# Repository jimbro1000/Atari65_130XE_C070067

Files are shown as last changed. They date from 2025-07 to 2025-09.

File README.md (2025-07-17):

# Atari 65/130XE Reproduction

## Introduction

This project reproduces the PCB used in the Atari 65XE and 130XE.
There are several variations on the board, this targets the
earlier design that used 8 or 16 4164 DRAM chips. These boards are
marked as C070065 or C070067

The initial primary goal is to support diagnostics rather than
create replacement boards but this will likely become possible as 
the project progresses.

### Sponsorship and Support

A bare donor board has been provided by Lee of "More Fun Making It"
and founder of the Retro Hardware Discord to save my working board 
from being torn down.

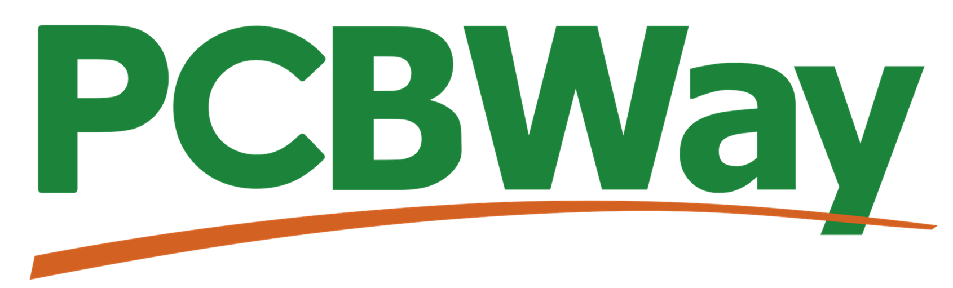
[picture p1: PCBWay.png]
PCBWay Logo


PCBWay are sponsoring the initial fabrication of the board by covering
the costs and providing high quality, rapid turnaround prototyping
capabilities.

An honourable mention also goes to Henry of the Retro Hardware Discord
for providing spares to help fix my 65XE (and thus negating the direct 
need for any of the work here)

### Sources

The schematics that the design is taken from are themselves copies
of the original work.

The primary source of information is taken from an updated version
of the Atari workshop manual updated and reproduced by JER/Eightbitter.
A second source comes from earlier reproduction drawings by Jerzy Sobola.

## Interactive Bill of Materials

The initial output of the project will be a web based interactive bill
of materials that includes trace routing. This allows visual 
identification of individual traces on the board and the devices each
trace connects to.

## Engineering Files

Once the accuracy of the reproduction is verified the project output
will include gerber files to facilitate the fabrication of boards.

### Accuracy

While every effort is made to ensure that the board design is accurate
and faithful to the original, there will be variations in tolerances that
result in the need for fettling of the board to correctly fit the
original case.

The board design provided will be a direct copy in terms of the components
used and as such will require original parts, some of which are
effectively unobtainable other than from donor machines - notably the SIO
port, expansion port and half of the custom chips. 

The SALLY CPU chip can be replaced with an adapted 65C02 to add the missing
HALT signal. FREDDIE and POKEY are available as reproductions. The PIA can 
be replaced with a MC68B21 (or equivalent).

## Progress

Revision 1 of the schematics and board design is complete, awaiting fabrication and test. Some tweaks to the schematic have been made to
match the donor board. The factory bodge for the GTIA select line has
been incorporated into the design, this has resulted in some 
alterations to routing but leaves a much tidier board when completed.

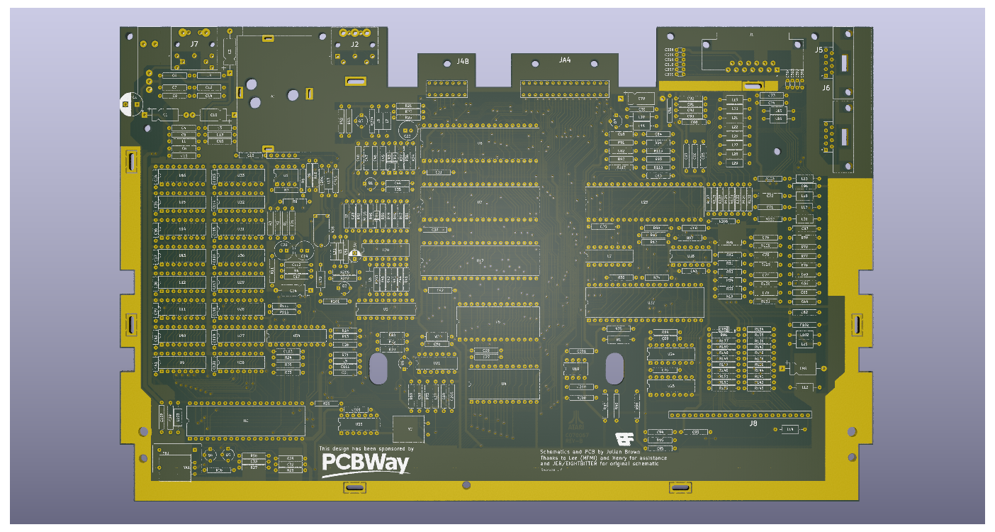
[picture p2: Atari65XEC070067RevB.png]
Render of PCB top


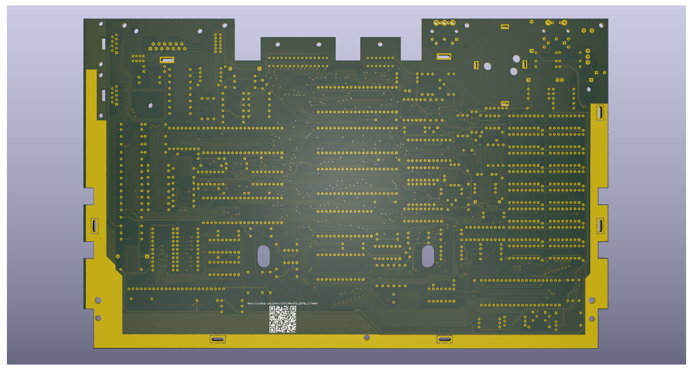
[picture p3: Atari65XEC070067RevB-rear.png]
Render of PCB rear


## References

FREDDIE replacement - design by Candle'O'Sin. Sold by Retro Lemon in two 
flavours:  
* https://retrolemon.co.uk/atari-8bit-upgrades/182-freddie-cpld.html
* https://retrolemon.co.uk/atari-8bit-upgrades/81-freddie-module.html
  (only for use with matching SRAM module)

SALLY conversion - open source project you can fabricate (or have fabricated 
for you)
* https://github.com/TheByteAttic/Sally-to-W65C02S-adapter
* https://www.pcbway.com/project/shareproject/6502__W65C02S__to_Atari_SALLY_adapter_Board.html

POKEY replacement (and upgrade) - design by Retronics. Sold by Retro Lemon:
* https://retrolemon.co.uk/atari-8bit-upgrades/148-pokeymax.html

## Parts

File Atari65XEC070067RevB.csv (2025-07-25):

Reference | Qty | Value | Footprint | DigiKey
C1 | 1 | 470uF | Capacitor_THT:CP_Radial_D10.0mm_P5.00mm | 732-9156-1-ND
C2,C3,C10,C79 | 4 | 22uF | Capacitor_THT:CP_Axial_L11.0mm_D5.0mm_P18.00mm_Horizontal | 1572-1393-ND
C4,C13,C16,C18,C26,C27,C28,C29,C30,C31,C34,C35,C36,C37,C38,C39,C40,C41,C42,C43,C51,C58,C61,C62,C68,C69,C70,C93,C101,C103,C105,C113,C114,C115,C116,C117,C118,C119,C120,C200,C201 | 41 | 100nF | Library:C_Axial_L3.8mm_D2.6mm_P8.89mm_Horizontal,Library:C_Axial_L5.1mm_D2.7mm_P12.72mm_Horizontal | 1109PHCT-ND
C5,C6,C8,C9,C12,C14,C15,C21,C45,C46,C47,C48,C63,C64,C65,C66,C71,C72,C73,C74,C75,C76,C77,C78,C80,C81,C82,C83,C84,C85,C86,C87,C88,C89,C90,C91,C92,C96,C97,C102,C112 | 41 | 1nF | Library:C_Axial_L5.1mm_D2.7mm_P12.72mm_Horizontal | 1216PHCT-ND
C7,C11,C94,C95 | 4 | 10nF | Library:C_Axial_L5.1mm_D2.7mm_P12.72mm_Horizontal | 1103PHCT-ND
C17,C23 | 2 | 47nF | Library:C_Axial_L5.1mm_D2.7mm_P12.72mm_Horizontal | 1107PHCT-ND
C19,C20,C22 | 3 | 4u7^{*} | Library:CE_NP_Radial_D8.0mm_P2.50mm | 475BPS100M-ND
C24,C98 | 2 | 10uF | Capacitor_THT:CP_Axial_L10.0mm_D4.5mm_P15.00mm_Horizontal,Capacitor_THT:CP_Axial_L11.0mm_D5.0mm_P18.00mm_Horizontal | 1572-1035-1-ND
C25 | 1 | 150pF | Library:C_Axial_L5.1mm_D2.7mm_P12.72mm_Horizontal | 399-4456-1-ND
C32 | 1 | 18pF | Library:C_Axial_L5.1mm_D2.7mm_P12.72mm_Horizontal | 1013PHCT-ND
C33 | 1 | 10pF | Library:C_Axial_L5.1mm_D2.7mm_P12.72mm_Horizontal | 1011PHCT-ND
C44 | 1 | 68pF | Library:C_Axial_L5.1mm_D2.7mm_P12.72mm_Horizontal | 1018PHCT-ND
C50 | 1 | 10uF | Capacitor_THT:CP_Radial_D5.0mm_P2.50mm | 399-18269-1-ND
C59 | 1 | 22pF | Library:C_Axial_L5.1mm_D2.7mm_P12.72mm_Horizontal | 1014PHCT-ND
C60 | 1 | 56pF | Library:C_Axial_L5.1mm_D2.7mm_P12.72mm_Horizontal | 399-C410C510FAG5TA-ND
C111 | 1 | 820pF | Library:C_Axial_L5.1mm_D2.7mm_P12.72mm_Horizontal | 399-C410C821K1R5TA-ND
C204,C205 | 2 | 1uF | Library:C_Axial_L5.1mm_D2.7mm_P12.72mm_Horizontal | 399-C410C105K5R5TA7200CT-ND
C206 | 1 | 27pF | Library:C_Axial_L5.1mm_D2.7mm_P12.72mm_Horizontal | 1015PHCT-ND
CR2,CR3,CR4,CR5 | 4 | 1N4148 | Diode_THT:D_DO-35_SOD27_P12.70mm_Horizontal | 1N4148FS-ND
L1,L2,L3,L5,L7,L9,L10,L11,L12,L23,L30,L31,L37,L102 | 14 | FB,FB or 470R | Inductor_THT:L_Axial_L7.0mm_D3.3mm_P12.70mm_Horizontal_Fastron_MICC,Library:R_Axial_L9.0mm_D2.7mm_P12.70mm_Horizontal | 1934-1310-ND
L6,L32,L103 | 3 | 100uH | Inductor_THT:L_Axial_L7.0mm_D3.3mm_P12.70mm_Horizontal_Fastron_MICC | 595-SFAPI-101K-UL-TRCT-ND
L14 | 1 | 22uH | Inductor_THT:L_Axial_L7.0mm_D3.3mm_P12.70mm_Horizontal_Fastron_MICC | 541-IRF24ER220JCT-ND
L15,L16,L17,L18,L19,L20,L21,L22,L25,L26,L27,L28,L29 | 13 | 10uH | Inductor_THT:L_Axial_L7.0mm_D3.3mm_P12.70mm_Horizontal_Fastron_MICC | 535-AICC-02-100K-TCT-ND
Q1,Q2,Q3,Q4,Q5,Q6 | 6 | 2N3904 | Library:TO-92L_Inline_Wide | 4878-2N3904CT-ND
Q7 | 1 | MPSA55 | Library:TO-92L_Inline_Wide | PN2907ABUFS-ND
R1 | 1 | 22k | Library:R_Axial_L9.0mm_D2.7mm_P12.70mm_Horizontal | CF14JT22K0CT-ND
R2,R7,R52 | 3 | 2k | Library:R_Axial_L9.0mm_D2.7mm_P12.70mm_Horizontal | CF14JT2K00CT-ND
R3 | 1 | 6k2 | Library:R_Axial_L9.0mm_D2.7mm_P12.70mm_Horizontal | CF14JT6K20CT-ND
R4,R39 | 2 | 56k | Library:R_Axial_L9.0mm_D2.7mm_P12.70mm_Horizontal | CF14JT56K0CT-ND
R5,R200 | 2 | 470k | Library:R_Axial_L9.0mm_D2.7mm_P12.70mm_Horizontal | S470KQCT-ND
R6 | 1 | 68k | Library:R_Axial_L9.0mm_D2.7mm_P12.70mm_Horizontal | CF14JT68K0CT-ND
R8 | 1 | 5k1 | Library:R_Axial_L9.0mm_D2.7mm_P12.70mm_Horizontal | CF14JT5K10CT-ND
R9,R23,R24,R25,R203,R206 | 6 | 3k3 | Library:R_Axial_L9.0mm_D2.7mm_P12.70mm_Horizontal | CF14JT3K30CT-ND
R10,R70 | 2 | 10k | Library:R_Axial_L9.0mm_D2.7mm_P12.70mm_Horizontal | CF14JT10K0CT-ND
R11,R26 | 2 | 2k2 | Library:R_Axial_L9.0mm_D2.7mm_P12.70mm_Horizontal | CF14JT2K20CT-ND
R12,R15,R19,R20,R21,R22,R30,R31,R33,R74,R75,R85,R86,R87,R88 | 15 | 3k | Library:R_Axial_L9.0mm_D2.7mm_P12.70mm_Horizontal | CF14JT3K00CT-ND
R13,R14,R34,R37,R41,R42,R43,R44,R45,R72,R73,R80 | 12 | 1k | Library:R_Axial_L9.0mm_D2.7mm_P12.70mm_Horizontal | CF14JT1K00CT-ND
R18,R27,R95,R120,R121,R122,R123,R124,R125,R126,R127,R132,R133,R134,R135,R136 | 16 | 220R | Library:R_Axial_L9.0mm_D2.7mm_P12.70mm_Horizontal | CF14JT220RCT-ND
R28 | 1 | 910k | Library:R_Axial_L9.0mm_D2.7mm_P12.70mm_Horizontal | CF14JT910KCT-ND
R29 | 1 | 1M | Library:R_Axial_L9.0mm_D2.7mm_P12.70mm_Horizontal | CF14JT1M00CT-ND
R35 | 1 | 33k | Library:R_Axial_L9.0mm_D2.7mm_P12.70mm_Horizontal | CF14JT33K0CT-ND
R36 | 1 | 680R | Library:R_Axial_L9.0mm_D2.7mm_P12.70mm_Horizontal | CF14JT680RCT-ND
R38 | 1 | 500k | Library:Potentiometer_Bourns_3352E_Vertical | 3352E-504LF-ND
R40,R53,R90,R117,R118,R119,R128,R129,R130,R131 | 10 | 100R | Library:R_Axial_L9.0mm_D2.7mm_P12.70mm_Horizontal | CF14JT100RCT-ND
R46 | 1 | 1k6 | Library:R_Axial_L9.0mm_D2.7mm_P12.70mm_Horizontal | CF14JT1K60CT-ND
R47 | 1 | 36k | Library:R_Axial_L9.0mm_D2.7mm_P12.70mm_Horizontal | CF14JT36K0CT-ND
R48 | 1 | 18k | Library:R_Axial_L9.0mm_D2.7mm_P12.70mm_Horizontal | CF14JT18K0CT-ND
R49 | 1 | 9K1 | Library:R_Axial_L9.0mm_D2.7mm_P12.70mm_Horizontal | CF14JT9K10CT-ND
R50,R81,R82,R83,R84,R92,R93,R94 | 8 | 4k7 | Library:R_Axial_L9.0mm_D2.7mm_P12.70mm_Horizontal | CF14JT4K70CT-ND
R51 | 1 | 750R | Library:R_Axial_L9.0mm_D2.7mm_P12.70mm_Horizontal | CF14JT750RCT-ND
R69,R201 | 2 | 6k8 | Library:R_Axial_L9.0mm_D2.7mm_P12.70mm_Horizontal | CF14JT6K80CT-ND
R71 | 1 | 470R | Library:R_Axial_L9.0mm_D2.7mm_P12.70mm_Horizontal | CF14JT470RCT-ND
R76,R77,R78,R79 | 4 | 1k8 | Library:R_Axial_L9.0mm_D2.7mm_P12.70mm_Horizontal | CF14JT1K80CT-ND
R89,R96 | 2 | 47k | Library:R_Axial_L9.0mm_D2.7mm_P12.70mm_Horizontal | S47KQCT-ND
R91 | 1 | 2k7 | Library:R_Axial_L9.0mm_D2.7mm_P12.70mm_Horizontal | CF14JT2K70CT-ND
R110,R111 | 2 | 33R | Library:R_Axial_L9.0mm_D2.7mm_P12.70mm_Horizontal | CF14JT33R0CT-ND
R116 | 1 | 51R | Library:R_Axial_L9.0mm_D2.7mm_P12.70mm_Horizontal | CF14JT51R0CT-ND
R137,R138,R139,R140,R141,R142,R143,R144,R145,R146,R147,R148,R149,R150,R151,R152,R153 | 17 | 270R | Library:R_Axial_L9.0mm_D2.7mm_P12.70mm_Horizontal | CF14JT270RCT-ND
R202 | 1 | 180R | Library:R_Axial_L9.0mm_D2.7mm_P12.70mm_Horizontal | CF14JT180RCT-ND
R204 | 1 | 47R | Library:R_Axial_L9.0mm_D2.7mm_P12.70mm_Horizontal | CF14JT47R0CT-ND
R205 | 1 | 150R | Library:R_Axial_L9.0mm_D2.7mm_P12.70mm_Horizontal | CF14JT150RCT-ND
U1 | 1 | LM358 | Package_DIP:DIP-8_W7.62mm | 296-1395-5-ND
U2 | 1 | 74LS138 | Package_DIP:DIP-16_W7.62mm | 296-1639-5-ND
U18 | 1 | 74LS08 | Package_DIP:DIP-14_W7.62mm | 296-1633-5-ND
U19 | 1 | NE555P | Package_DIP:DIP-8_W7.62mm | 296-NE555P-ND
U20 | 1 | 4050 | Package_DIP:DIP-16_W7.62mm | 296-2056-ND
U21 | 1 | 74LS74 | Package_DIP:DIP-14_W7.62mm | 296-1668-5-ND
U24,U25 | 2 | 4051 | Package_DIP:DIP-16_W7.62mm | 296-2057-5-ND
Y2 | 1 | 4.33618MHz | Crystal:Crystal_HC49-U_Horizontal | X1013-ND
YA1 | 1 | See Note | Crystal:Crystal_HC49-U_Horizontal | 535-AB-14.31818MHZ-B2CT-ND
YB1 | 1 | See Note | Oscillator:Oscillator_DIP-14 | X946-ND

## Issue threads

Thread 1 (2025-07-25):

Mounting hole alignment

jimbro1000, 2025-07-25:
Accuracy is about 95% for most mounting points but require attention, especially for three points. The two keyboard support cutouts need aligning horizontally. The horizontal shield mounting point on the north west corner of the board needs moving vertically

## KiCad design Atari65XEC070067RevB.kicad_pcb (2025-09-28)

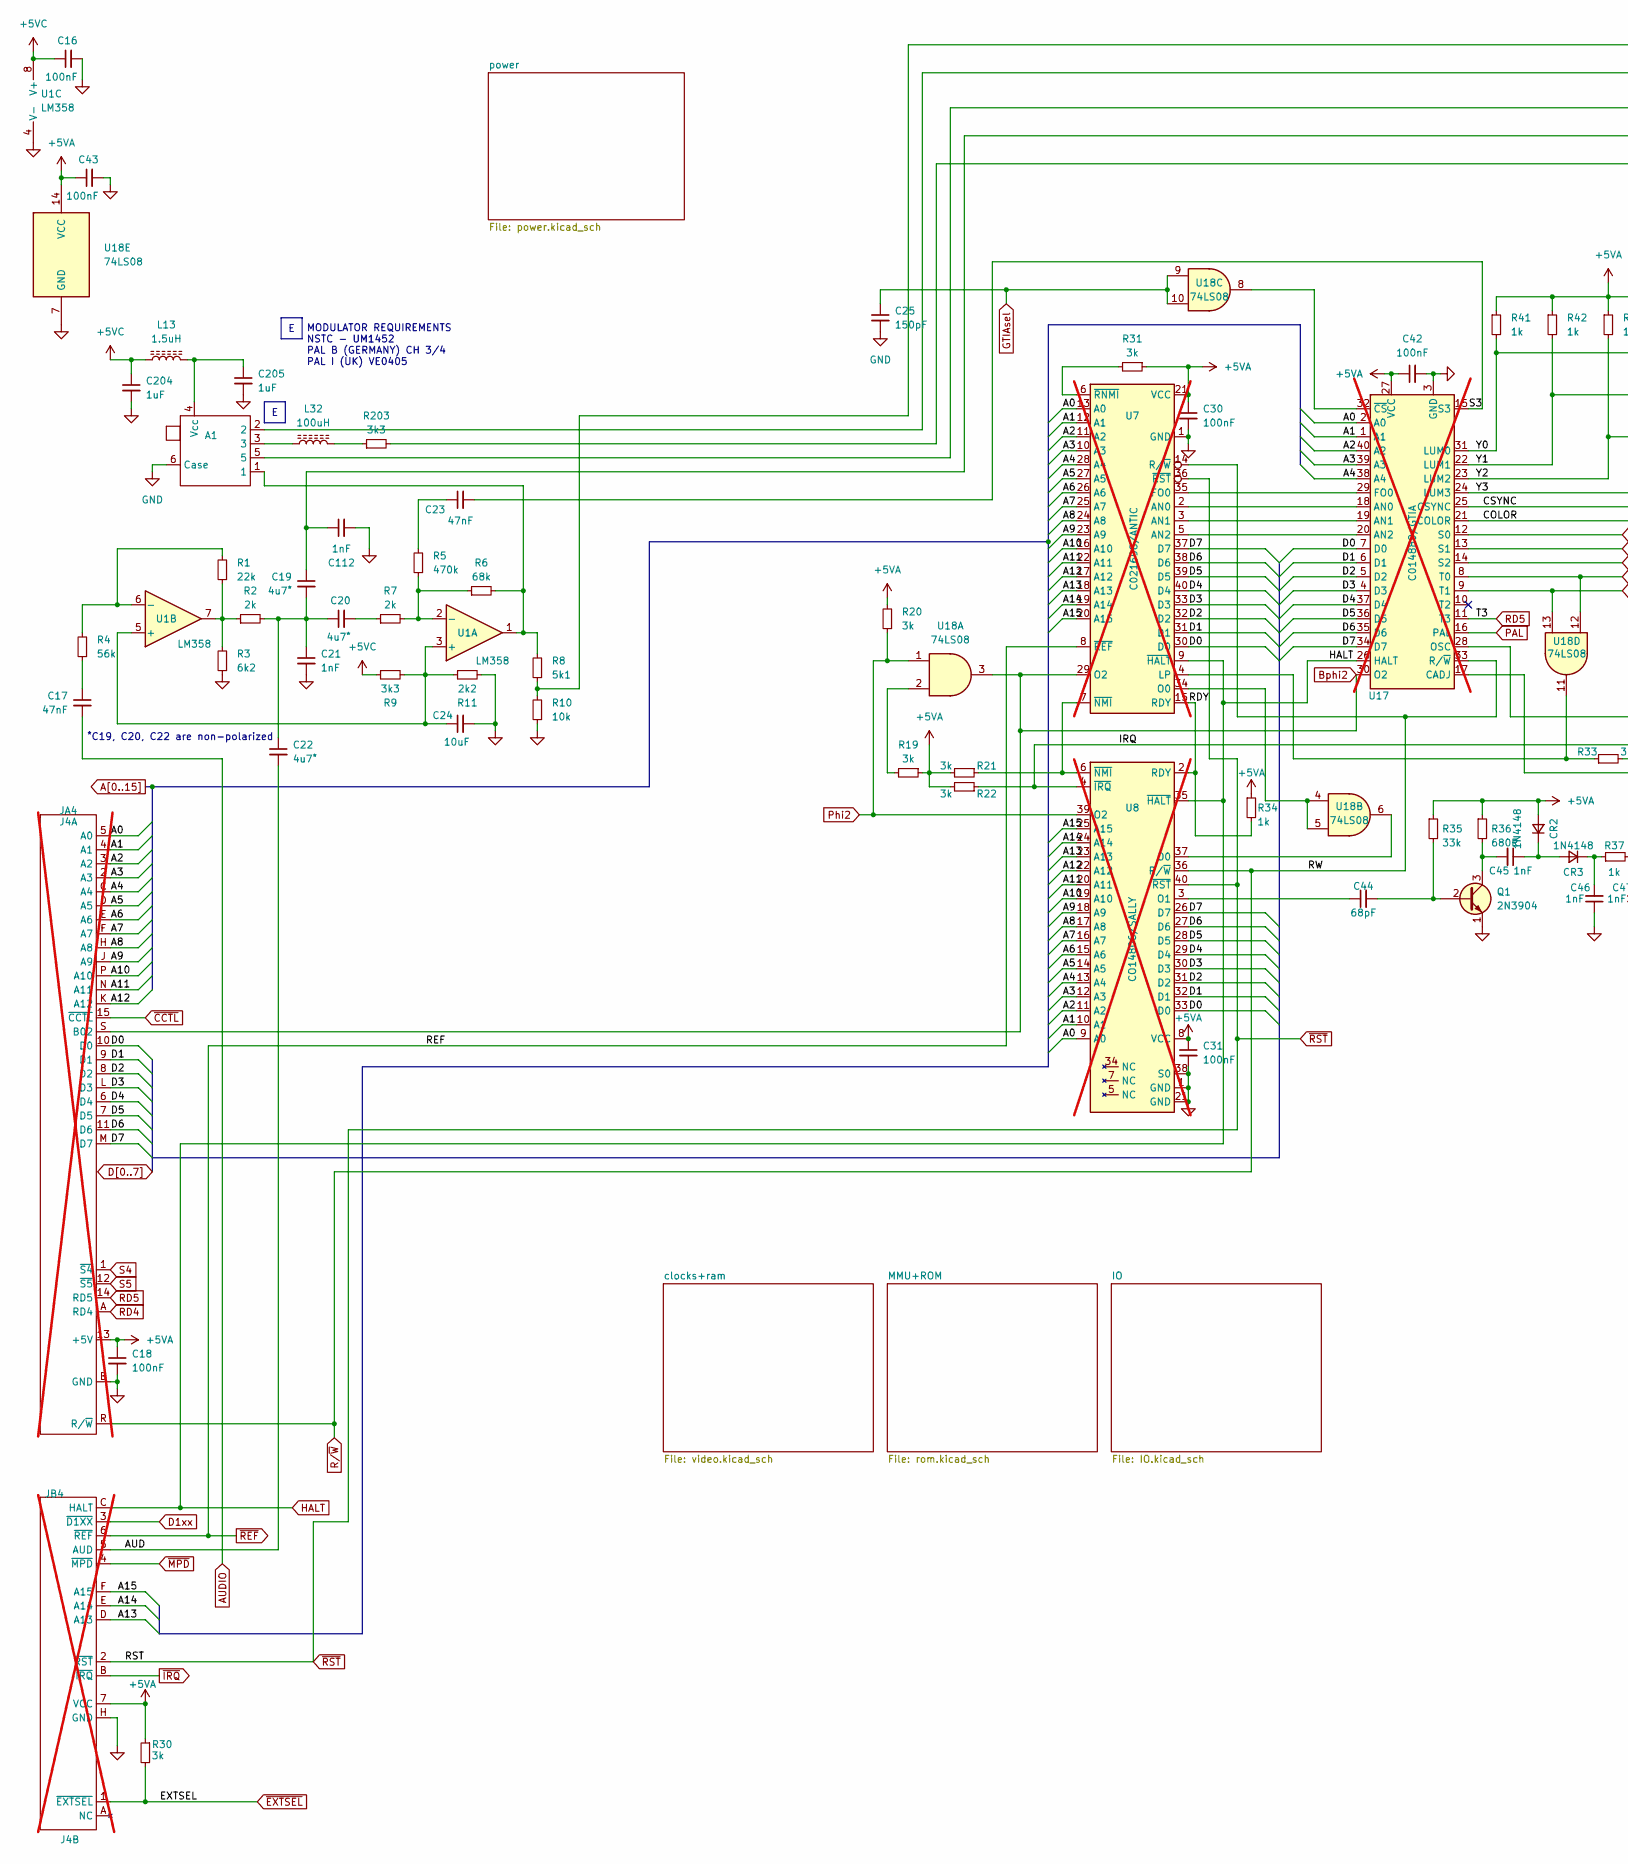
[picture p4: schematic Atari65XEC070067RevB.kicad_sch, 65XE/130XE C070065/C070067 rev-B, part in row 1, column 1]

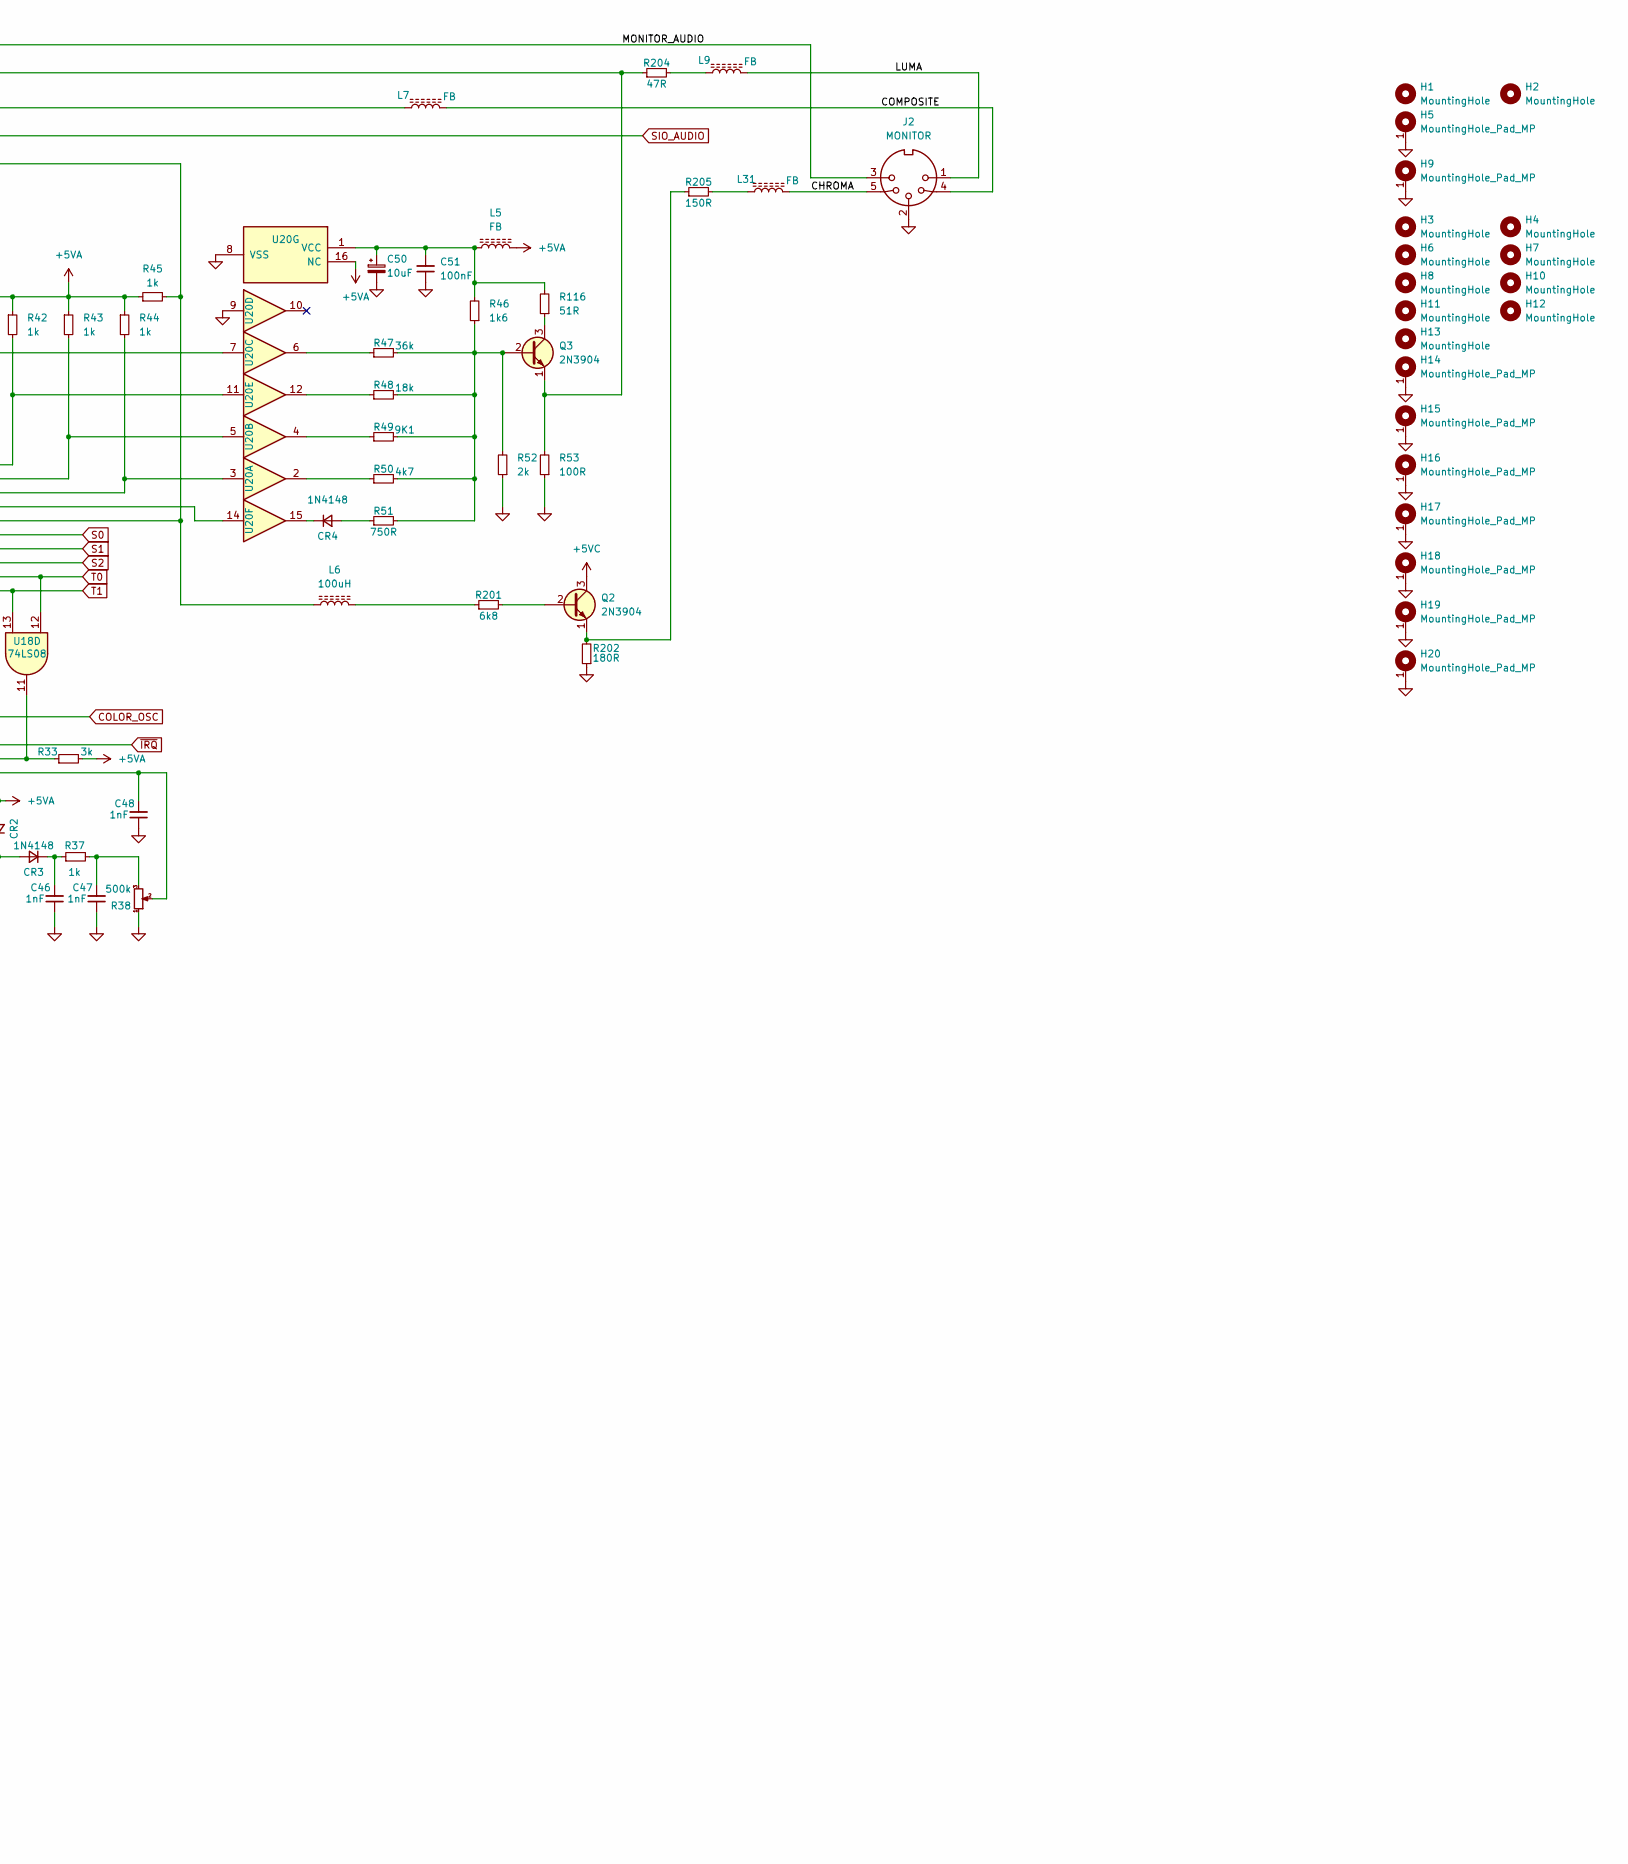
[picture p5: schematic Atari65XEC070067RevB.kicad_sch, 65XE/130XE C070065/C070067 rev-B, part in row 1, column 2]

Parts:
A1: RF_Modulator_MDG-UB360S
C16, C18, C30, C31, C42, C43, C51: 100nF; C_Axial_L5.1mm_D2.7mm_P12.72mm_Horizontal; DigiKey 1109PHCT-ND
C17, C23: 47nF; C_Axial_L5.1mm_D2.7mm_P12.72mm_Horizontal; DigiKey 1107PHCT-ND
C19, C20, C22: 4u7^{*}; CE_NP_Radial_D8.0mm_P2.50mm; DigiKey 475BPS100M-ND
C21, C45, C46, C47, C48, C112: 1nF; C_Axial_L5.1mm_D2.7mm_P12.72mm_Horizontal; DigiKey 1216PHCT-ND
C24: 10uF; CP_Axial_L10.0mm_D4.5mm_P15.00mm_Horizontal; DigiKey 1572-1035-1-ND
C25: 150pF; C_Axial_L5.1mm_D2.7mm_P12.72mm_Horizontal; DigiKey 399-4456-1-ND
C44: 68pF; C_Axial_L5.1mm_D2.7mm_P12.72mm_Horizontal; DigiKey 1018PHCT-ND
C50: 10uF; CP_Radial_D5.0mm_P2.50mm; DigiKey 399-18269-1-ND
C204, C205: 1uF; C_Axial_L5.1mm_D2.7mm_P12.72mm_Horizontal; DigiKey 399-C410C105K5R5TA7200CT-ND
CR2, CR3, CR4: 1N4148; D_DO-35_SOD27_P12.70mm_Horizontal; DigiKey 1N4148FS-ND
H1, H2: MountingHole; Cutout
H3, H4, H6, H7, H8, H10, H11, H12, H13: MountingHole; MountingHole_3.2mm_M3_DIN965
H5, H9: MountingHole_Pad_MP; MountingHole_4.3mm_M4_ISO7380_Pad_TopBottom
H14, H15, H16, H17, H18, H19, H20: MountingHole_Pad_MP; Untitled
J2: MONITOR; CUI_SDS-50J; DigiKey CP-2350-ND
JA4: J4A; CARTRIDGE; not fitted
JB4: J4B; EXPANSION; not fitted
L5, L7, L9, L31: FB; L_Axial_L7.0mm_D3.3mm_P12.70mm_Horizontal_Fastron_MICC; DigiKey 1934-1417-1-ND
L6, L32: 100uH; L_Axial_L7.0mm_D3.3mm_P12.70mm_Horizontal_Fastron_MICC; DigiKey 118-78F101J-TR-RCCT-ND
L13: 1.5uH; L_Axial_L7.0mm_D3.3mm_P12.70mm_Horizontal_Fastron_MICC; DigiKey 78F1R5K-RC-ND
Q1, Q2, Q3: 2N3904; TO-92L_Inline_Wide; DigiKey 4878-2N3904CT-ND
R1: 22k; R_Axial_L9.0mm_D2.7mm_P12.70mm_Horizontal; DigiKey CF14JT22K0CT-ND
R2, R7, R52: 2k; R_Axial_L9.0mm_D2.7mm_P12.70mm_Horizontal; DigiKey CF14JT2K00CT-ND
R3: 6k2; R_Axial_L9.0mm_D2.7mm_P12.70mm_Horizontal; DigiKey CF14JT6K20CT-ND
R4: 56k; R_Axial_L9.0mm_D2.7mm_P12.70mm_Horizontal; DigiKey CF14JT56K0CT-ND
R5: 470k; R_Axial_L9.0mm_D2.7mm_P12.70mm_Horizontal; DigiKey S470KQCT-ND
R6: 68k; R_Axial_L9.0mm_D2.7mm_P12.70mm_Horizontal; DigiKey CF14JT68K0CT-ND
R8: 5k1; R_Axial_L9.0mm_D2.7mm_P12.70mm_Horizontal; DigiKey CF14JT5K10CT-ND
R9, R203: 3k3; R_Axial_L9.0mm_D2.7mm_P12.70mm_Horizontal; DigiKey CF14JT3K30CT-ND
R10: 10k; R_Axial_L9.0mm_D2.7mm_P12.70mm_Horizontal; DigiKey CF14JT10K0CT-ND
R11: 2k2; R_Axial_L9.0mm_D2.7mm_P12.70mm_Horizontal; DigiKey CF14JT2K20CT-ND
R19, R20, R21, R22, R30, R31, R33: 3k; R_Axial_L9.0mm_D2.7mm_P12.70mm_Horizontal; DigiKey CF14JT3K00CT-ND
R34, R37, R41, R42, R43, R44, R45: 1k; R_Axial_L9.0mm_D2.7mm_P12.70mm_Horizontal; DigiKey CF14JT1K00CT-ND
R35: 33k; R_Axial_L9.0mm_D2.7mm_P12.70mm_Horizontal; DigiKey CF14JT33K0CT-ND
R36: 680R; R_Axial_L9.0mm_D2.7mm_P12.70mm_Horizontal; DigiKey CF14JT680RCT-ND
R38: 500k; Potentiometer_Bourns_3352E_Vertical; DigiKey 3352E-504LF-ND
R46: 1k6; R_Axial_L9.0mm_D2.7mm_P12.70mm_Horizontal; DigiKey CF14JT1K60CT-ND
R47: 36k; R_Axial_L9.0mm_D2.7mm_P12.70mm_Horizontal; DigiKey CF14JT36K0CT-ND
R48: 18k; R_Axial_L9.0mm_D2.7mm_P12.70mm_Horizontal; DigiKey CF14JT18K0CT-ND
R49: 9K1; R_Axial_L9.0mm_D2.7mm_P12.70mm_Horizontal; DigiKey CF14JT9K10CT-ND
R50: 4k7; R_Axial_L9.0mm_D2.7mm_P12.70mm_Horizontal; DigiKey CF14JT4K70CT-ND
R51: 750R; R_Axial_L9.0mm_D2.7mm_P12.70mm_Horizontal; DigiKey CF14JT750RCT-ND
R53: 100R; R_Axial_L9.0mm_D2.7mm_P12.70mm_Horizontal; DigiKey CF14JT100RCT-ND
R116: 51R; R_Axial_L9.0mm_D2.7mm_P12.70mm_Horizontal; DigiKey CF14JT51R0CT-ND
R201: 6k8; R_Axial_L9.0mm_D2.7mm_P12.70mm_Horizontal; DigiKey CF14JT6K80CT-ND
R202: 180R; R_Axial_L9.0mm_D2.7mm_P12.70mm_Horizontal; DigiKey CF14JT180RCT-ND
R204: 47R; R_Axial_L9.0mm_D2.7mm_P12.70mm_Horizontal; DigiKey CF14JT47R0CT-ND
R205: 150R; R_Axial_L9.0mm_D2.7mm_P12.70mm_Horizontal; DigiKey CF14JT150RCT-ND
U1: LM358; DIP-8_W7.62mm; DigiKey 296-1395-5-ND
U7: C021698/ANTIC; DIP-40_W15.24mm; not fitted
U8: CO14806/SALLY; DIP-40_W15.24mm; not fitted
U17: C014889/GTIA; DIP-40_W15.24mm; not fitted
U18: 74LS08; DIP-14_W7.62mm; DigiKey 296-1633-5-ND
U20: 4050; DIP-16_W7.62mm; DigiKey 296-2056-ND

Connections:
+5VA: C18.1, C30.1, C31.1, C42.1, C43.1, CR2.2 (A), JA4.13 (+5V), JB4.7 (VCC), L5.2, R19.1, R20.2, R21.2, R22.2, R30.1, R31.1, R33.2, R34.1, R35.1, R36.1, R41.1, R42.1, R43.1, R44.1, R45.1, U7.21 (VCC), U8.8 (VCC), U17.27 (VCC), U18.14 (VCC), U20.16 (NC); also elsewhere on the board
+5VC: C16.1, C204.1, L13.1, Q2.3 (C), R9.1, U1.8 (V+); also elsewhere on the board
/AUD: C22.2, JB4.5 (AUD)
/CHROMA: J2.5, L31.2
/COLOR: L6.1, R45.2, R203.2, U17.21 (COLOR)
/COMPOSITE: J2.4, L7.2
/CSYNC: U17.25 (CSYNC), U20.14
/LUMA: J2.1, L9.2
/MONITOR_AUDIO: J2.3, R8.1, R10.2
/RDY: R34.2, U7.15 (RDY), U8.2 (RDY)
/S3: C23.2, U17.15 (S3)
/Y0: R41.2, U17.31 (LUM0), U20.7
/Y1: R42.2, U17.22 (LUM1), U20.11
/Y2: R43.2, U17.23 (LUM2), U20.5
/Y3: R44.2, U17.24 (LUM3), U20.3
A0: JA4.5 (A0), U7.13 (A0), U8.9 (A0), U17.2 (A0); also elsewhere on the board
A1: JA4.4 (A1), U7.12 (A1), U8.10 (A1), U17.1 (A1); also elsewhere on the board
A2: JA4.3 (A2), U7.11 (A2), U8.11 (A2), U17.40 (A2); also elsewhere on the board
A3: JA4.2 (A3), U7.10 (A3), U8.12 (A3), U17.39 (A3); also elsewhere on the board
A4: JA4.C (A4), U7.28 (A4), U8.13 (A4), U17.38 (A4); also elsewhere on the board
A5: JA4.D (A5), U7.27 (A5), U8.14 (A5); also elsewhere on the board
A6: JA4.E (A6), U7.26 (A6), U8.15 (A6); also elsewhere on the board
A7: JA4.F (A7), U7.25 (A7), U8.16 (A7); also elsewhere on the board
A8: JA4.H (A8), U7.24 (A8), U8.17 (A8); also elsewhere on the board
A9: JA4.J (A9), U7.23 (A9), U8.18 (A9); also elsewhere on the board
A10: JA4.P (A10), U7.16 (A10), U8.19 (A10); also elsewhere on the board
A11: JA4.N (A11), U7.22 (A11), U8.20 (A11); also elsewhere on the board
A12: JA4.K (A12), U7.17 (A12), U8.22 (A12); also elsewhere on the board
A13: JB4.D (A13), U7.18 (A13), U8.23 (A13); also elsewhere on the board
A14: JB4.E (A14), U7.19 (A14), U8.24 (A14); also elsewhere on the board
A15: JB4.F (A15), U7.20 (A15), U8.25 (A15); also elsewhere on the board
AUDIO: C17.2; also elsewhere on the board
Bphi2: JA4.S (B02), U7.29 (O2), U17.30 (O2), U18.3; also elsewhere on the board
COLOR_OSC: U17.28 (OSC); also elsewhere on the board
D0: JA4.10 (D0), U7.30 (D0), U8.33 (D0), U17.7 (D0); also elsewhere on the board
D1: JA4.9 (D1), U7.31 (D1), U8.32 (D1), U17.6 (D1); also elsewhere on the board
D1xx: JB4.3 (~D1XX); also elsewhere on the board
D2: JA4.8 (D2), U7.32 (D2), U8.31 (D2), U17.5 (D2); also elsewhere on the board
D3: JA4.L (D3), U7.33 (D3), U8.30 (D3), U17.4 (D3); also elsewhere on the board
D4: JA4.6 (D4), U7.40 (D4), U8.29 (D4), U17.37 (D4); also elsewhere on the board
D5: JA4.7 (D5), U7.39 (D5), U8.28 (D5), U17.36 (D5); also elsewhere on the board
D6: JA4.11 (D6), U7.38 (D6), U8.27 (D6), U17.35 (D6); also elsewhere on the board
D7: JA4.M (D7), U7.37 (D7), U8.26 (D7), U17.34 (D7); also elsewhere on the board
GND: A1.6 (Case), C16.2, C18.2, C21.2, C24.2, C25.2, C30.2, C31.2, C42.2, C43.2, C46.1, C47.1, C48.1, C50.2, C51.1, C112.2, C204.2, C205.2, H5.1, H9.1, H14.1, H15.1, H16.1, H17.1, H18.1, H19.1, H20.1, J2.2, JA4.B (GND), JB4.H (GND), Q1.1 (E), R3.1, R10.1, R11.2, R38.1, R52.1, R53.1, R202.1, U1.4 (V-), U7.1 (GND), U8.1 (GND), U8.21 (GND), U8.38 (S0), U17.3 (GND), U18.7 (GND), U20.8 (VSS), U20.9; also elsewhere on the board
GTIAsel: C25.1, U18.9, U18.10; also elsewhere on the board
HALT: JB4.C (HALT), U7.9 (~HALT), U8.35 (~HALT), U17.26 (HALT); also elsewhere on the board
unnamed: A1.1, R6.2, R8.2, U1.1
unnamed: A1.3, L32.1
unnamed: A1.5, L7.1
unnamed: A1.4 (Vcc), C205.1, L13.2
unnamed: C17.1, R4.1
unnamed: C19.2, C20.1, C21.1, C22.1, R2.2
unnamed: C20.2, R7.1
unnamed: C23.1, R5.2
unnamed: C47.2, R37.2, R38.3
unnamed: C45.1, CR2.1 (K), CR3.2 (A)
unnamed: C46.2, CR3.1 (K), R37.1
unnamed: CR4.2 (A), R51.1
unnamed: CR4.1 (K), U20.15
unnamed: L6.2, R201.1
unnamed: L9.1, R204.2
unnamed: L31.1, R205.2
unnamed: L32.2, R203.1
unnamed: C44.2, Q1.2 (B), R35.2
unnamed: C45.2, Q1.3 (C), R36.2
unnamed: Q2.2 (B), R201.2
unnamed: Q2.1 (E), R202.2, R205.1
unnamed: Q3.2 (B), R46.1, R47.2, R48.2, R49.2, R50.2, R51.2, R52.2
unnamed: Q3.3 (C), R116.1
unnamed: A1.2, Q3.1 (E), R53.2, R204.1
unnamed: R1.1, R2.1, R3.2, U1.7
unnamed: R19.2, U18.2
unnamed: R47.1, U20.6
unnamed: R48.1, U20.12
unnamed: R49.1, U20.4
unnamed: R50.1, U20.2
unnamed: C24.1, R9.2, R11.1, U1.3 (+), U1.5 (+)
unnamed: R5.1, R6.1, R7.2, U1.2 (-)
unnamed: R1.2, R4.2, U1.6 (-)
unnamed: R33.1, U7.4 (LP), U18.11
unnamed: U7.34 (O0), U18.4, U18.5
unnamed: R21.1, U7.7 (~NMI), U8.6 (~NMI)
unnamed: R31.2, U7.6 (~RNMI)
unnamed: U8.37 (O0), U18.6
unnamed: C44.1, U8.3 (O1)
unnamed: U7.2 (AN0), U17.18 (AN0)
unnamed: U7.3 (AN1), U17.19 (AN1)
unnamed: U7.5 (AN2), U17.20 (AN2)
unnamed: C48.2, R38.2, U17.17 (CADJ)
unnamed: U7.35 (FO0), U17.29 (FO0)
unnamed: U17.32 (~CS), U18.8
unnamed: C50.1, C51.2, L5.1, R46.2, R116.2, U20.1 (VCC)
PAL: U17.16 (PAL); also elsewhere on the board
Phi2: R20.1, U8.39 (O2), U18.1; also elsewhere on the board
RD4: JA4.A (RD4); also elsewhere on the board
RD5: JA4.14 (RD5), U17.11 (T3); also elsewhere on the board
R/~W: JA4.R (R/~W), U7.14 (R/~W), U8.36 (R/~W), U17.33 (R/~W); also elsewhere on the board
S0: U17.12 (S0); also elsewhere on the board
S1: U17.13 (S1); also elsewhere on the board
S2: U17.14 (S2); also elsewhere on the board
S4: JA4.1 (~S4); also elsewhere on the board
S5: JA4.12 (~S5); also elsewhere on the board
SIO_AUDIO: C19.1, C112.1; also elsewhere on the board
T0: U17.8 (T0), U18.12; also elsewhere on the board
T1: U17.9 (T1), U18.13; also elsewhere on the board
~CCTL: JA4.15 (~CCTL); also elsewhere on the board
~EXTSEL: JB4.1 (~EXTSEL), R30.2; also elsewhere on the board
~IRQ: JB4.B (~IRQ), R22.1, U8.4 (~IRQ); also elsewhere on the board
~MPD: JB4.4 (~MPD); also elsewhere on the board
~REF: JB4.6 (~REF), U7.8 (~REF); also elsewhere on the board
~RST: JB4.2 (~RST), U7.36 (~RST), U8.40 (~RST); also elsewhere on the board

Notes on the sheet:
MODULATOR REQUIREMENTS NSTC - UM1452 PAL B (GERMANY) CH 3/4 PAL I (UK) VE0405
^{*}C19, C20, C22 are non-polarized

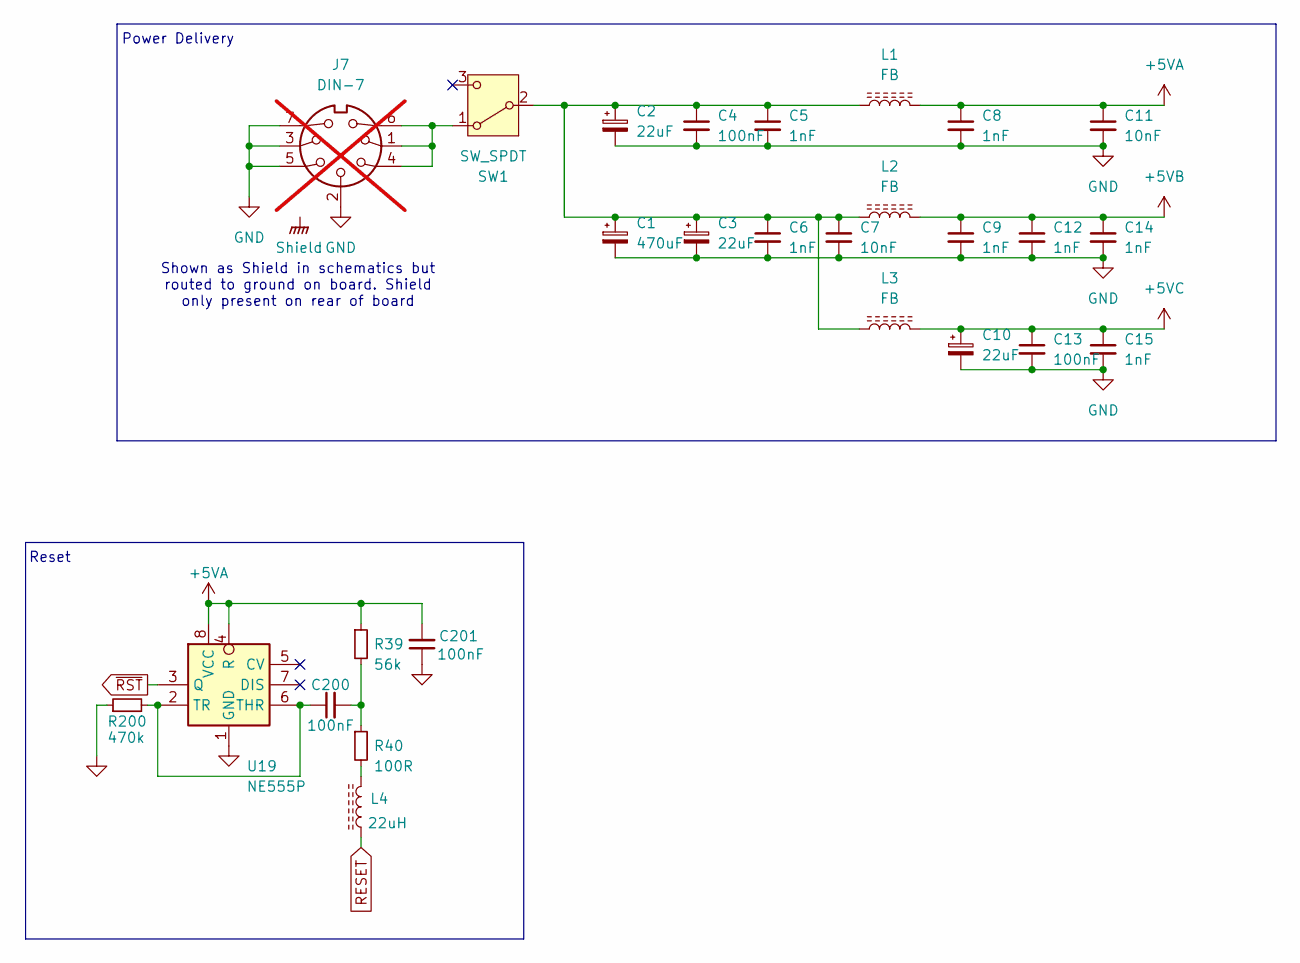
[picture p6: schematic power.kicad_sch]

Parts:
C1: 470uF; CP_Radial_D10.0mm_P5.00mm; DigiKey 732-9156-1-ND
C2, C3, C10: 22uF; CP_Axial_L11.0mm_D5.0mm_P18.00mm_Horizontal; DigiKey 1572-1393-ND
C4, C13, C200, C201: 100nF; C_Axial_L5.1mm_D2.7mm_P12.72mm_Horizontal; DigiKey 1109PHCT-ND
C5, C6, C8, C9, C12, C14, C15: 1nF; C_Axial_L5.1mm_D2.7mm_P12.72mm_Horizontal; DigiKey 1216PHCT-ND
C7, C11: 10nF; C_Axial_L5.1mm_D2.7mm_P12.72mm_Horizontal; DigiKey 1103PHCT-ND
J7: DIN-7; CUI_SDS-70J_Atari; not fitted
L1, L2, L3: FB; R_Axial_L9.0mm_D2.7mm_P12.70mm_Horizontal; DigiKey 1934-1417-1-ND
L4: 22uH; L_Axial_L7.0mm_D3.3mm_P12.70mm_Horizontal_Fastron_MICC; DigiKey 541-IRF24ER220JCT-ND
R39: 56k; R_Axial_L9.0mm_D2.7mm_P12.70mm_Horizontal; DigiKey CF14JT56K0CT-ND
R40: 100R; R_Axial_L9.0mm_D2.7mm_P12.70mm_Horizontal; DigiKey CF14JT100RCT-ND
R200: 470k; R_Axial_L9.0mm_D2.7mm_P12.70mm_Horizontal; DigiKey S470KQCT-ND
SW1: SW_SPDT; PowerSwitch
U19: NE555P; DIP-8_W7.62mm; DigiKey 296-NE555P-ND

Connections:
+5VA: C8.1, C11.1, C201.2, L1.2, R39.1, U19.4 (R), U19.8 (VCC); also elsewhere on the board
+5VB: C9.1, C12.1, C14.1, L2.2; also elsewhere on the board
+5VC: C10.1, C13.1, C15.1, L3.2; also elsewhere on the board
GND: C1.2, C2.2, C3.2, C4.2, C5.2, C6.2, C7.2, C8.2, C9.2, C10.2, C11.2, C12.2, C13.2, C14.2, C15.2, C201.1, J7.2, J7.3, J7.5, J7.7, R200.1, U19.1 (GND); also elsewhere on the board
unnamed: C200.2, R39.2, R40.1
unnamed: L4.2, R40.2
unnamed: J7.1, J7.4, J7.6, SW1.1 (A)
unnamed: C1.1, C2.1, C3.1, C4.1, C5.1, C6.1, C7.1, L1.1, L2.1, L3.1, SW1.2 (B)
unnamed: C200.1, R200.2, U19.2 (TR), U19.6 (THR)
RESET: L4.1; also elsewhere on the board
~RST: U19.3 (Q); also elsewhere on the board

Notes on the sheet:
Power Delivery
Shown as Shield in schematics but routed to ground on board. Shield only present on rear of board
Reset

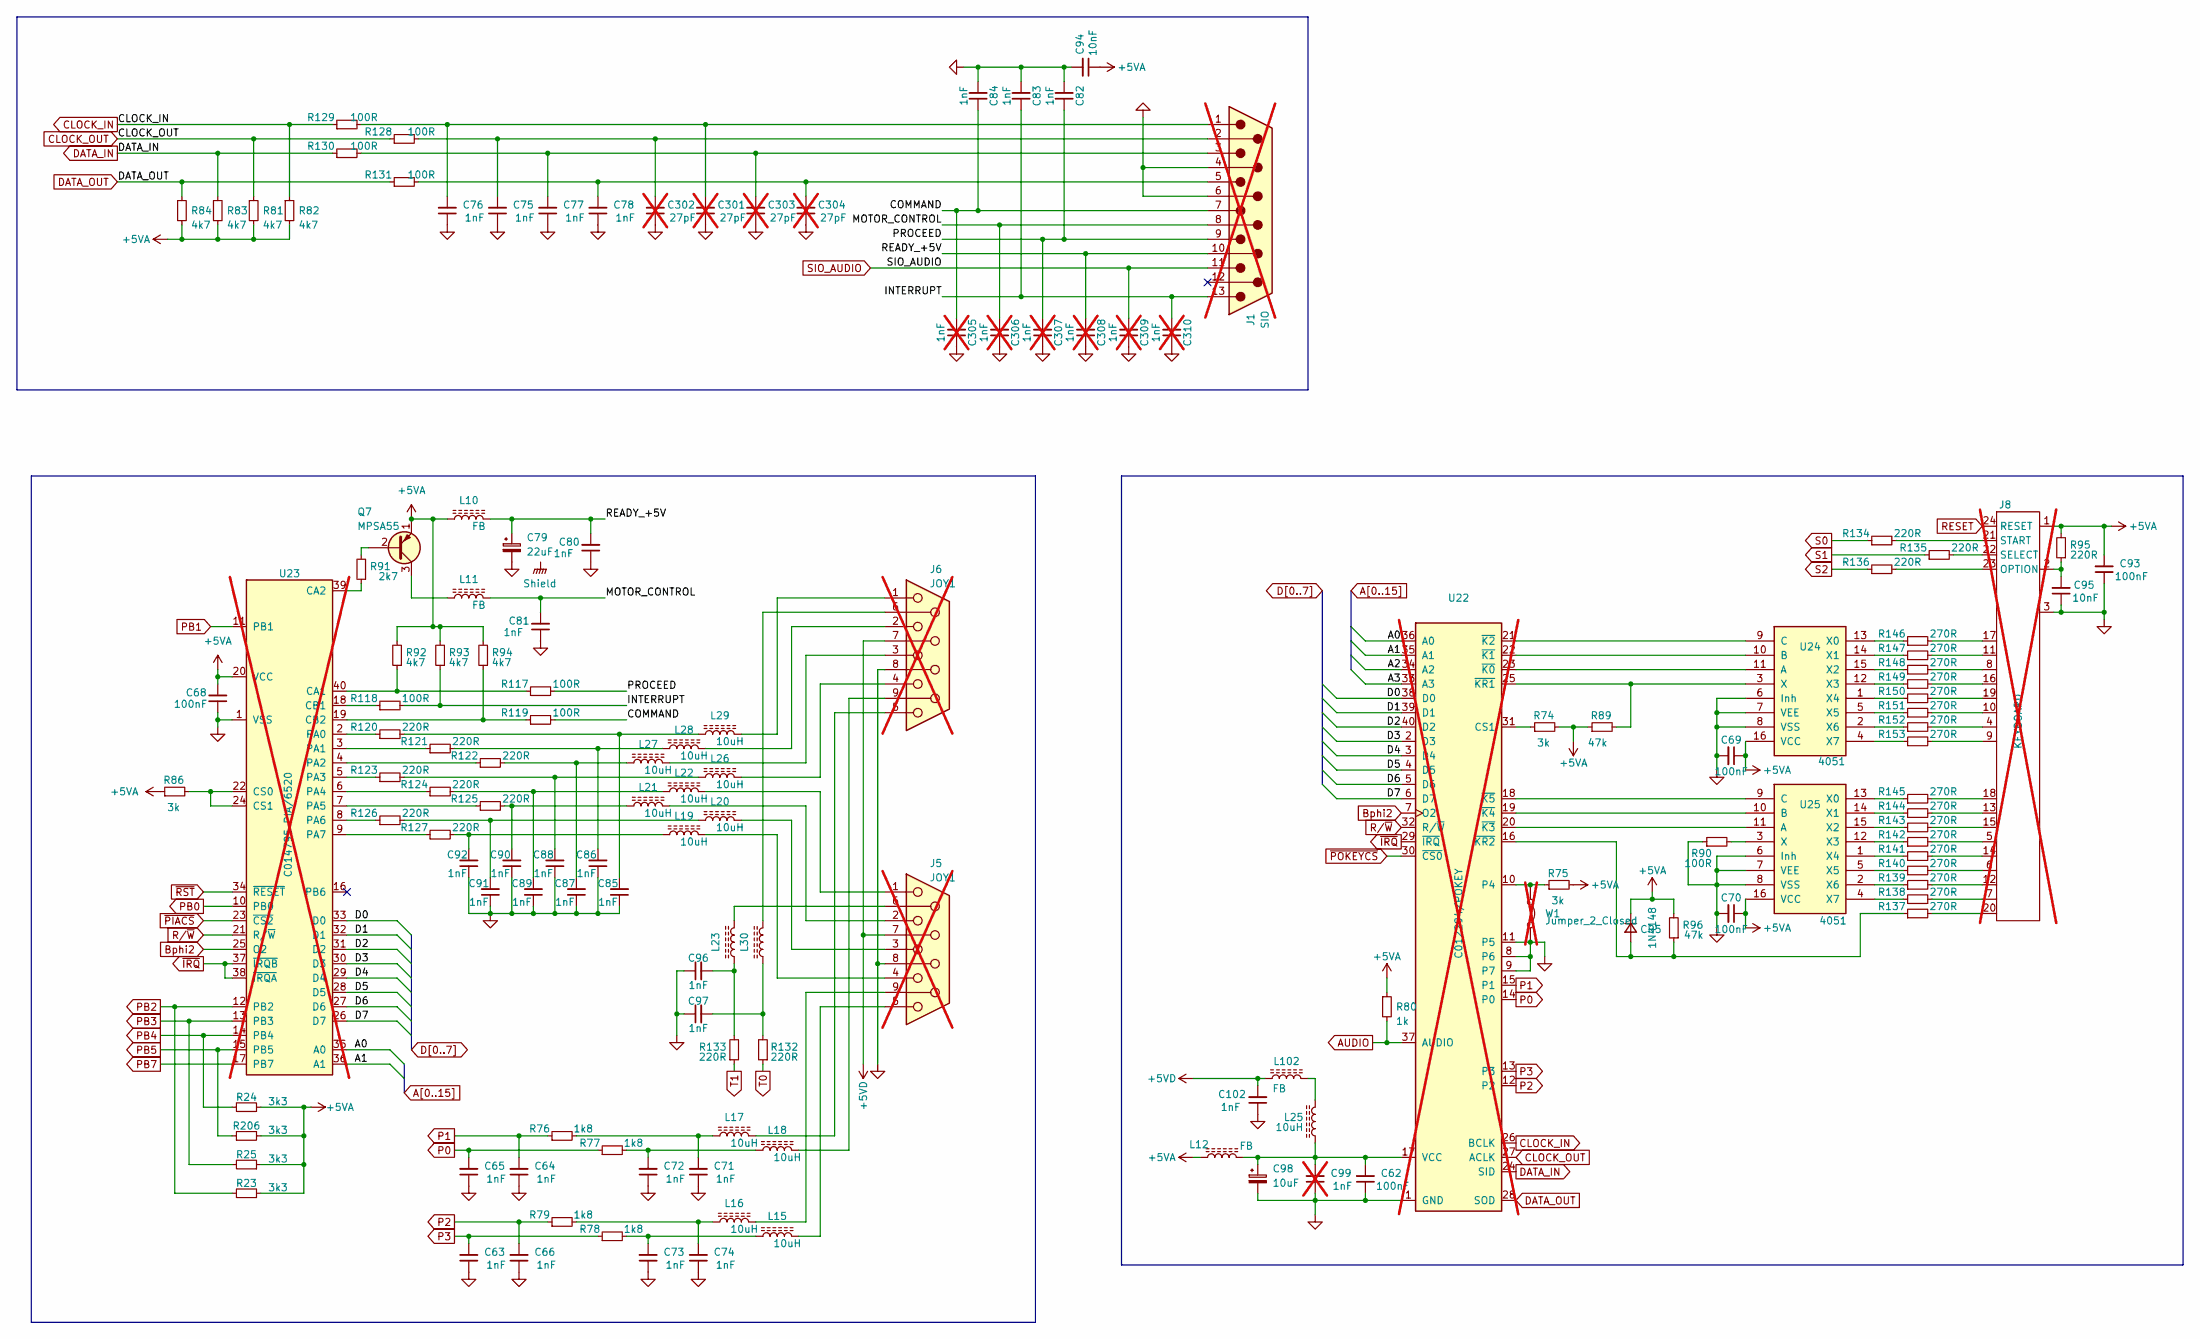
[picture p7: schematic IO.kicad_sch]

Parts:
C62, C68, C69, C70, C93: 100nF; C_Axial_L5.1mm_D2.7mm_P12.72mm_Horizontal; DigiKey 1109PHCT-ND
C63, C64, C65, C66, C71, C72, C73, C74, C75, C76, C77, C78, C80, C81, C82, C83, C84, C85, C86, C87, C88, C89, C90, C91, C92, C96, C97, C102: 1nF; C_Axial_L5.1mm_D2.7mm_P12.72mm_Horizontal; DigiKey 1216PHCT-ND
C79: 22uF; CP_Axial_L11.0mm_D5.0mm_P18.00mm_Horizontal; DigiKey 1572-1393-ND
C94, C95: 10nF; C_Axial_L5.1mm_D2.7mm_P12.72mm_Horizontal; DigiKey 1103PHCT-ND
C98: 10uF; CP_Axial_L11.0mm_D5.0mm_P18.00mm_Horizontal; DigiKey 1572-1035-1-ND
C99: 1nF; C_Axial_L5.1mm_D2.7mm_P12.72mm_Horizontal; DigiKey 1216PHCT-ND; not fitted
C301, C302, C303, C304: 27pF; C_Disc_D3.0mm_W1.6mm_P3.0mm; not fitted
C305, C306, C307, C308, C309, C310: 1nF; C_Disc_D3.0mm_W1.6mm_P3.0mm; not fitted
CR5: 1N4148; D_DO-35_SOD27_P12.70mm_Horizontal; DigiKey 1N4148FS-ND
J1: SIO; DSUB-13_Pins_Horizontal_P2.77x2.84mm_EdgePinOffset7.70mm_Ho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; not fitted
J5, J6: JOY1; DSUB-9_Pins_Horizontal_P2.77x2.54mm_Atari; not fitted
J8: KEYBOARD; not fitted
L10, L11, L12, L23, L30, L102: FB; L_Axial_L7.0mm_D3.3mm_P12.70mm_Horizontal_Fastron_MICC; DigiKey 1934-1417-1-ND
L15, L16, L17, L18, L19, L20, L21, L22, L25, L26, L27, L28, L29: 10uH; L_Axial_L7.0mm_D3.3mm_P12.70mm_Horizontal_Fastron_MICC; DigiKey 535-AICC-02-100K-TCT-ND
Q7: MPSA55; TO-92L_Inline_Wide; DigiKey PN2907ABUFS-ND
R23, R24, R25, R206: 3k3; R_Axial_L9.0mm_D2.7mm_P12.70mm_Horizontal; DigiKey CF14JT3K30CT-ND
R74, R75, R86: 3k; R_Axial_L9.0mm_D2.7mm_P12.70mm_Horizontal; DigiKey CF14JT3K00CT-ND
R76, R77, R78, R79: 1k8; R_Axial_L9.0mm_D2.7mm_P12.70mm_Horizontal; DigiKey CF14JT1K80CT-ND
R80: 1k; R_Axial_L9.0mm_D2.7mm_P12.70mm_Horizontal; DigiKey CF14JT1K00CT-ND
R81, R82, R83, R84, R92, R93, R94: 4k7; R_Axial_L9.0mm_D2.7mm_P12.70mm_Horizontal; DigiKey CF14JT4K70CT-ND
R89, R96: 47k; R_Axial_L9.0mm_D2.7mm_P12.70mm_Horizontal; DigiKey S47KQCT-ND
R90, R117, R118, R119, R128, R129, R130, R131: 100R; R_Axial_L9.0mm_D2.7mm_P12.70mm_Horizontal; DigiKey CF14JT100RCT-ND
R91: 2k7; R_Axial_L9.0mm_D2.7mm_P12.70mm_Horizontal; DigiKey CF14JT2K70CT-ND
R95, R120, R121, R122, R123, R124, R125, R126, R127, R132, R133, R134, R135, R136: 220R; R_Axial_L9.0mm_D2.7mm_P12.70mm_Horizontal; DigiKey CF14JT220RCT-ND
R137, R138, R139, R140, R141, R142, R143, R144, R145, R146, R147, R148, R149, R150, R151, R152, R153: 270R; R_Axial_L9.0mm_D2.7mm_P12.70mm_Horizontal; DigiKey CF14JT270RCT-ND
U22: C012294/POKEY; DIP-40_W15.24mm; not fitted
U23: C014795 PIA/6520; DIP-40_W15.24mm; not fitted
U24, U25: 4051; DIP-16_W7.62mm; DigiKey 296-2057-5-ND
W1: Jumper_2_Closed; R_Axial_DIN0309_L9.0mm_D3.2mm_P12.70mm_Horizontal; not fitted

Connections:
+5VA: C68.2, C69.1, C70.1, C93.2, C94.1, CR5.1 (K), J8.1, L10.1, L12.1, Q7.1 (E), R23.1, R24.1, R25.1, R74.2, R75.2, R80.1, R81.2, R82.2, R83.2, R84.2, R86.1, R89.1, R92.2, R93.2, R94.2, R95.2, R96.2, R206.2, U23.20 (VCC), U24.16 (VCC), U25.16 (VCC); also elsewhere on the board
+5VD: C102.2, J5.7, J6.7, L102.1
/IO/COMMAND: C84.1, C305.2, J1.7, R119.2
/IO/INTERRUPT: C83.1, C310.2, J1.13, R93.1, R118.2
/IO/MOTOR_CONTROL: C81.2, C306.2, J1.8, L11.2
/IO/PROCEED: C82.1, C307.2, J1.9, R117.2
/IO/READY_+5V: C79.1, C80.2, C308.2, J1.10, L10.2
A0: U22.36 (A0), U23.35 (A0); also elsewhere on the board
A1: U22.35 (A1), U23.36 (A1); also elsewhere on the board
A2: U22.34 (A2); also elsewhere on the board
A3: U22.33 (A3); also elsewhere on the board
AUDIO: R80.2, U22.37 (AUDIO); also elsewhere on the board
Bphi2: U22.7 (O2), U23.25 (O2); also elsewhere on the board
CLOCK_IN: R82.1, R129.1, U22.26 (BCLK)
CLOCK_OUT: R81.1, R128.1, U22.27 (ACLK)
D0: U22.38 (D0), U23.33 (D0); also elsewhere on the board
D1: U22.39 (D1), U23.32 (D1); also elsewhere on the board
D2: U22.40 (D2), U23.31 (D2); also elsewhere on the board
D3: U22.2 (D3), U23.30 (D3); also elsewhere on the board
D4: U22.3 (D4), U23.29 (D4); also elsewhere on the board
D5: U22.4 (D5), U23.28 (D5); also elsewhere on the board
D6: U22.5 (D6), U23.27 (D6); also elsewhere on the board
D7: U22.6 (D7), U23.26 (D7); also elsewhere on the board
DATA_IN: R83.1, R130.1, U22.24 (SID)
DATA_OUT: R84.1, R131.1, U22.28 (SOD)
GND: C62.1, C63.1, C64.1, C65.1, C66.1, C68.1, C69.2, C70.2, C71.1, C72.1, C73.1, C74.1, C75.1, C76.1, C77.1, C78.1, C79.2, C80.1, C81.1, C82.2, C83.2, C84.2, C85.1, C86.1, C87.1, C88.1, C89.1, C90.1, C91.1, C92.1, C93.1, C94.2, C95.1, C96.1, C97.1, C98.2, C99.1, C102.1, C301.1, C302.1, C303.1, C304.1, C305.1, C306.1, C307.1, C308.1, C309.1, C310.1, J1.4, J1.6, J5.8, J6.8, J8.3, R90.1, U22.1 (GND), U22.8 (P6), U22.9 (P7), U22.11 (P5), U23.1 (VSS), U24.6 (Inh), U24.7 (VEE), U24.8 (VSS), U25.6 (Inh), U25.7 (VEE), U25.8 (VSS), W1.2 (B); also elsewhere on the board
unnamed: C71.2, L17.1, R76.2
unnamed: C72.2, L18.1, R77.2
unnamed: C73.2, L15.1, R78.2
unnamed: C74.2, L16.1, R79.2
unnamed: C85.2, L29.1, R120.2
unnamed: C86.2, L28.1, R121.2
unnamed: C87.2, L27.1, R122.2
unnamed: C88.2, L26.1, R123.2
unnamed: C89.2, L22.1, R124.2
unnamed: C90.2, L21.1, R125.2
unnamed: C91.2, L20.1, R126.2
unnamed: C92.2, L19.1, R127.2
unnamed: C95.2, J8.2, R95.1
unnamed: C96.2, L23.1, R133.2
unnamed: C97.2, L30.1, R132.2
unnamed: C76.2, C301.2, J1.1, R129.2
unnamed: C75.2, C302.2, J1.2, R128.2
unnamed: C77.2, C303.2, J1.3, R130.2
unnamed: C78.2, C304.2, J1.5, R131.2
unnamed: CR5.2 (A), R96.1, R137.1, U22.16 (~KR2)
unnamed: J5.1, L22.2
unnamed: J5.2, L21.2
unnamed: J5.3, L20.2
unnamed: J5.4, L19.2
unnamed: J5.5, L15.2
unnamed: J5.6, L23.2
unnamed: J5.9, L16.2
unnamed: J6.1, L29.2
unnamed: J6.2, L28.2
unnamed: J6.3, L27.2
unnamed: J6.4, L26.2
unnamed: J6.5, L17.2
unnamed: J6.6, L30.2
unnamed: J6.9, L18.2
unnamed: J8.23 (OPTION), R136.2
unnamed: J8.4, R152.2
unnamed: J8.5, R142.2
unnamed: J8.6, R140.2
unnamed: J8.7, R138.2
unnamed: J8.8, R148.2
unnamed: J8.9, R153.2
unnamed: J8.10, R151.2
unnamed: J8.11, R147.2
unnamed: J8.12, R139.2
unnamed: J8.13, R144.2
unnamed: J8.14, R141.2
unnamed: J8.15, R143.2
unnamed: J8.16, R149.2
unnamed: J8.17, R146.2
unnamed: J8.18, R145.2
unnamed: J8.19, R150.2
unnamed: J8.20, R137.2
unnamed: J8.22 (SELECT), R135.2
unnamed: J8.21 (START), R134.2
unnamed: L25.2, L102.2
unnamed: Q7.2 (B), R91.2
unnamed: L11.1, Q7.3 (C)
unnamed: R74.1, U22.31 (CS1)
unnamed: R75.1, U22.10 (P4), W1.1 (A)
unnamed: C62.2, C98.1, C99.2, L12.2, L25.1, U22.17 (VCC)
unnamed: U22.23 (~K0), U24.11 (A)
unnamed: U22.22 (~K1), U24.10 (B)
unnamed: U22.21 (~K2), U24.9 (C)
unnamed: U22.20 (~K3), U25.11 (A)
unnamed: U22.19 (~K4), U25.10 (B)
unnamed: U22.18 (~K5), U25.9 (C)
unnamed: R89.2, U22.25 (~KR1), U24.3 (X)
unnamed: R92.1, R117.1, U23.40 (CA1)
unnamed: R91.1, U23.39 (CA2)
unnamed: R118.1, U23.18 (CB1)
unnamed: R94.1, R119.1, U23.19 (CB2)
unnamed: R86.2, U23.22 (CS0), U23.24 (CS1)
unnamed: R120.1, U23.2 (PA0)
unnamed: R121.1, U23.3 (PA1)
unnamed: R122.1, U23.4 (PA2)
unnamed: R123.1, U23.5 (PA3)
unnamed: R124.1, U23.6 (PA4)
unnamed: R125.1, U23.7 (PA5)
unnamed: R126.1, U23.8 (PA6)
unnamed: R127.1, U23.9 (PA7)
unnamed: R146.1, U24.13 (X0)
unnamed: R147.1, U24.14 (X1)
unnamed: R148.1, U24.15 (X2)
unnamed: R149.1, U24.12 (X3)
unnamed: R150.1, U24.1 (X4)
unnamed: R151.1, U24.5 (X5)
unnamed: R152.1, U24.2 (X6)
unnamed: R153.1, U24.4 (X7)
unnamed: R145.1, U25.13 (X0)
unnamed: R144.1, U25.14 (X1)
unnamed: R143.1, U25.15 (X2)
unnamed: R142.1, U25.12 (X3)
unnamed: R141.1, U25.1 (X4)
unnamed: R140.1, U25.5 (X5)
unnamed: R139.1, U25.2 (X6)
unnamed: R138.1, U25.4 (X7)
unnamed: R90.2, U25.3 (X)
P0: C65.2, R77.1, U22.14 (P0)
P1: C64.2, R76.1, U22.15 (P1)
P2: C66.2, R79.1, U22.12 (P2)
P3: C63.2, R78.1, U22.13 (P3)
PB0: U23.10 (PB0); also elsewhere on the board
PB1: U23.11 (PB1); also elsewhere on the board
PB2: R23.2, U23.12 (PB2); also elsewhere on the board
PB3: R25.2, U23.13 (PB3); also elsewhere on the board
PB4: R24.2, U23.14 (PB4); also elsewhere on the board
PB5: R206.1, U23.15 (PB5); also elsewhere on the board
PB7: U23.17 (PB7); also elsewhere on the board
RESET: J8.24 (RESET); also elsewhere on the board
R/~W: U22.32 (R/~W), U23.21 (R/~W); also elsewhere on the board
S0: R134.1; also elsewhere on the board
S1: R135.1; also elsewhere on the board
S2: R136.1; also elsewhere on the board
SIO_AUDIO: C309.2, J1.11; also elsewhere on the board
T0: R132.1; also elsewhere on the board
T1: R133.1; also elsewhere on the board
~IRQ: U22.29 (~IRQ), U23.37 (~IRQB), U23.38 (~IRQA); also elsewhere on the board
~PIACS: U23.23 (~CS2); also elsewhere on the board
~POKEYCS: U22.30 (~CS0); also elsewhere on the board
~RST: U23.34 (~RESET); also elsewhere on the board

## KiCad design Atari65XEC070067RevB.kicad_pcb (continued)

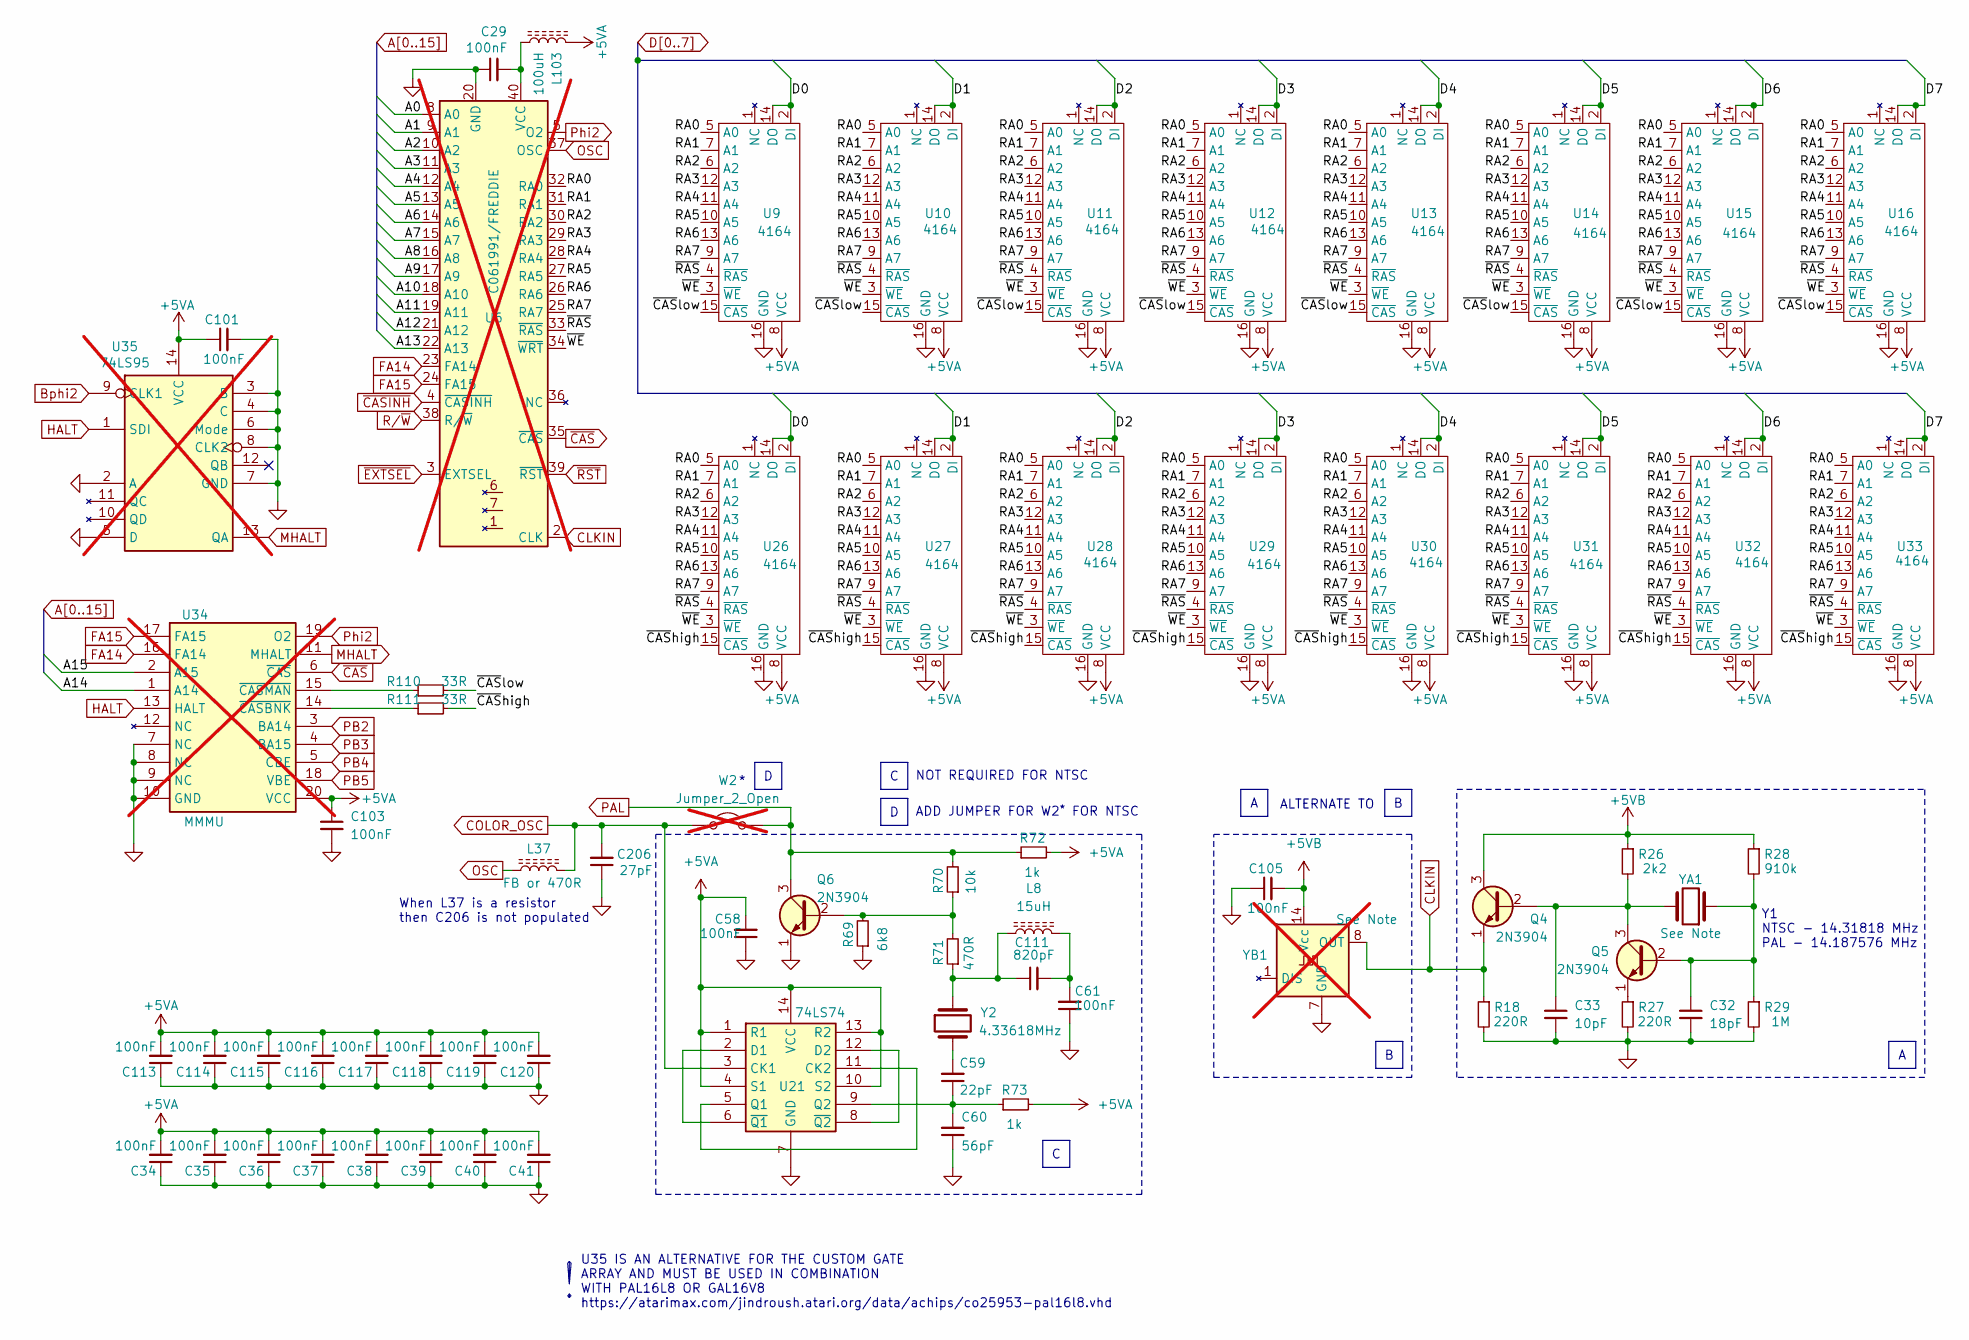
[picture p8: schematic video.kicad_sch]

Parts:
C29, C58, C61, C101, C103, C105: 100nF; C_Axial_L5.1mm_D2.7mm_P12.72mm_Horizontal; DigiKey 1109PHCT-ND
C32: 18pF; C_Axial_L5.1mm_D2.7mm_P12.72mm_Horizontal; DigiKey 1013PHCT-ND
C33: 10pF; C_Axial_L5.1mm_D2.7mm_P12.72mm_Horizontal; DigiKey 1011PHCT-ND
C34, C35, C36, C37, C38, C39, C40, C41, C113, C114, C115, C116, C117, C118, C119, C120: 100nF; C_Axial_L3.8mm_D2.6mm_P8.89mm_Horizontal; DigiKey 1109PHCT-ND
C59: 22pF; C_Axial_L5.1mm_D2.7mm_P12.72mm_Horizontal; DigiKey 1014PHCT-ND
C60: 56pF; C_Axial_L5.1mm_D2.7mm_P12.72mm_Horizontal; DigiKey 399-C410C510FAG5TA-ND
C111: 820pF; C_Axial_L5.1mm_D2.7mm_P12.72mm_Horizontal; DigiKey 399-C410C821K1R5TA-ND
C206: 27pF; C_Axial_L5.1mm_D2.7mm_P12.72mm_Horizontal; DigiKey 1015PHCT-ND
L8: 15uH; R_Axial_L9.0mm_D2.7mm_P12.70mm_Horizontal; DigiKey 78F150J-RC-ND
L37: FB or 470R; R_Axial_L9.0mm_D2.7mm_P12.70mm_Horizontal; DigiKey 1934-1417-1-ND
L103: 100uH; L_Axial_L7.0mm_D3.3mm_P12.70mm_Horizontal_Fastron_MICC; DigiKey 118-78F101J-TR-RCCT-ND
Q4, Q5, Q6: 2N3904; TO-92L_Inline_Wide; DigiKey 4878-2N3904CT-ND
R18, R27: 220R; R_Axial_L9.0mm_D2.7mm_P12.70mm_Horizontal; DigiKey CF14JT220RCT-ND
R26: 2k2; R_Axial_L9.0mm_D2.7mm_P12.70mm_Horizontal; DigiKey CF14JT2K20CT-ND
R28: 910k; R_Axial_L9.0mm_D2.7mm_P12.70mm_Horizontal; DigiKey CF14JT910KCT-ND
R29: 1M; R_Axial_L9.0mm_D2.7mm_P12.70mm_Horizontal; DigiKey CF14JT1M00CT-ND
R69: 6k8; R_Axial_L9.0mm_D2.7mm_P12.70mm_Horizontal; DigiKey CF14JT6K80CT-ND
R70: 10k; R_Axial_L9.0mm_D2.7mm_P12.70mm_Horizontal; DigiKey CF14JT10K0CT-ND
R71: 470R; R_Axial_L9.0mm_D2.7mm_P12.70mm_Horizontal; DigiKey CF14JT470RCT-ND
R72, R73: 1k; R_Axial_L9.0mm_D2.7mm_P12.70mm_Horizontal; DigiKey CF14JT1K00CT-ND
R110, R111: 33R; R_Axial_L9.0mm_D2.7mm_P12.70mm_Horizontal; DigiKey CF14JT33R0CT-ND
U6: C061991/FREDDIE; DIP-40_W15.24mm; not fitted
U9, U10, U11, U12, U13, U14, U15, U16, U26, U27, U28, U29, U30, U31, U32, U33: 4164; DIP-16_W7.62mm
U21: 74LS74; DIP-14_W7.62mm; DigiKey 296-1668-5-ND
U34: MMMU; DIP-20_W7.62mm; not fitted
U35: 74LS95; DIP-14_W7.62mm; not fitted
W2: Jumper_2_Open; R_Axial_DIN0309_L9.0mm_D3.2mm_P12.70mm_Horizontal; not fitted
Y2: 4.33618MHz; Crystal_HC49-U_Horizontal; DigiKey X1013-ND
YA1: See Note; Crystal_HC49-U_Horizontal; DigiKey 535-AB-14.31818MHZ-B2CT-ND
YB1: See Note; Oscillator_DIP-14; DigiKey X946-ND; not fitted

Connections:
+5VA: C34.2, C35.2, C36.2, C37.2, C38.2, C39.2, C40.2, C41.2, C58.2, C101.1, C103.1, C113.2, C114.2, C115.2, C116.2, C117.2, C118.2, C119.2, C120.2, L103.2, R72.2, R73.2, U9.8 (VCC), U10.8 (VCC), U11.8 (VCC), U12.8 (VCC), U13.8 (VCC), U14.8 (VCC), U15.8 (VCC), U16.8 (VCC), U21.1 (R1), U21.4 (S1), U21.10 (S2), U21.13 (R2), U21.14 (VCC), U26.8 (VCC), U27.8 (VCC), U28.8 (VCC), U29.8 (VCC), U30.8 (VCC), U31.8 (VCC), U32.8 (VCC), U33.8 (VCC), U34.20 (VCC), U35.14 (VCC); also elsewhere on the board
+5VB: C105.2, Q4.3 (C), R26.1, R28.1, YB1.14 (Vcc); also elsewhere on the board
/clocks+ram/RA0: U6.32 (RA0), U9.5 (A0), U10.5 (A0), U11.5 (A0), U12.5 (A0), U13.5 (A0), U14.5 (A0), U15.5 (A0), U16.5 (A0), U26.5 (A0), U27.5 (A0), U28.5 (A0), U29.5 (A0), U30.5 (A0), U31.5 (A0), U32.5 (A0), U33.5 (A0)
/clocks+ram/RA1: U6.31 (RA1), U9.7 (A1), U10.7 (A1), U11.7 (A1), U12.7 (A1), U13.7 (A1), U14.7 (A1), U15.7 (A1), U16.7 (A1), U26.7 (A1), U27.7 (A1), U28.7 (A1), U29.7 (A1), U30.7 (A1), U31.7 (A1), U32.7 (A1), U33.7 (A1)
/clocks+ram/RA2: U6.30 (RA2), U9.6 (A2), U10.6 (A2), U11.6 (A2), U12.6 (A2), U13.6 (A2), U14.6 (A2), U15.6 (A2), U16.6 (A2), U26.6 (A2), U27.6 (A2), U28.6 (A2), U29.6 (A2), U30.6 (A2), U31.6 (A2), U32.6 (A2), U33.6 (A2)
/clocks+ram/RA3: U6.29 (RA3), U9.12 (A3), U10.12 (A3), U11.12 (A3), U12.12 (A3), U13.12 (A3), U14.12 (A3), U15.12 (A3), U16.12 (A3), U26.12 (A3), U27.12 (A3), U28.12 (A3), U29.12 (A3), U30.12 (A3), U31.12 (A3), U32.12 (A3), U33.12 (A3)
/clocks+ram/RA4: U6.28 (RA4), U9.11 (A4), U10.11 (A4), U11.11 (A4), U12.11 (A4), U13.11 (A4), U14.11 (A4), U15.11 (A4), U16.11 (A4), U26.11 (A4), U27.11 (A4), U28.11 (A4), U29.11 (A4), U30.11 (A4), U31.11 (A4), U32.11 (A4), U33.11 (A4)
/clocks+ram/RA5: U6.27 (RA5), U9.10 (A5), U10.10 (A5), U11.10 (A5), U12.10 (A5), U13.10 (A5), U14.10 (A5), U15.10 (A5), U16.10 (A5), U26.10 (A5), U27.10 (A5), U28.10 (A5), U29.10 (A5), U30.10 (A5), U31.10 (A5), U32.10 (A5), U33.10 (A5)
/clocks+ram/RA6: U6.26 (RA6), U9.13 (A6), U10.13 (A6), U11.13 (A6), U12.13 (A6), U13.13 (A6), U14.13 (A6), U15.13 (A6), U16.13 (A6), U26.13 (A6), U27.13 (A6), U28.13 (A6), U29.13 (A6), U30.13 (A6), U31.13 (A6), U32.13 (A6), U33.13 (A6)
/clocks+ram/RA7: U6.25 (RA7), U9.9 (A7), U10.9 (A7), U11.9 (A7), U12.9 (A7), U13.9 (A7), U14.9 (A7), U15.9 (A7), U16.9 (A7), U26.9 (A7), U27.9 (A7), U28.9 (A7), U29.9 (A7), U30.9 (A7), U31.9 (A7), U32.9 (A7), U33.9 (A7)
/clocks+ram/~CAShigh: R111.2, U26.15 (~CAS), U27.15 (~CAS), U28.15 (~CAS), U29.15 (~CAS), U30.15 (~CAS), U31.15 (~CAS), U32.15 (~CAS), U33.15 (~CAS)
/clocks+ram/~CASlow: R110.2, U9.15 (~CAS), U10.15 (~CAS), U11.15 (~CAS), U12.15 (~CAS), U13.15 (~CAS), U14.15 (~CAS), U15.15 (~CAS), U16.15 (~CAS)
/clocks+ram/~RAS: U6.33 (~RAS), U9.4 (~RAS), U10.4 (~RAS), U11.4 (~RAS), U12.4 (~RAS), U13.4 (~RAS), U14.4 (~RAS), U15.4 (~RAS), U16.4 (~RAS), U26.4 (~RAS), U27.4 (~RAS), U28.4 (~RAS), U29.4 (~RAS), U30.4 (~RAS), U31.4 (~RAS), U32.4 (~RAS), U33.4 (~RAS)
/clocks+ram/~WE: U6.34 (~WRT), U9.3 (~WE), U10.3 (~WE), U11.3 (~WE), U12.3 (~WE), U13.3 (~WE), U14.3 (~WE), U15.3 (~WE), U16.3 (~WE), U26.3 (~WE), U27.3 (~WE), U28.3 (~WE), U29.3 (~WE), U30.3 (~WE), U31.3 (~WE), U32.3 (~WE), U33.3 (~WE)
A0: U6.8 (A0); also elsewhere on the board
A1: U6.9 (A1); also elsewhere on the board
A2: U6.10 (A2); also elsewhere on the board
A3: U6.11 (A3); also elsewhere on the board
A4: U6.12 (A4); also elsewhere on the board
A5: U6.13 (A5); also elsewhere on the board
A6: U6.14 (A6); also elsewhere on the board
A7: U6.15 (A7); also elsewhere on the board
A8: U6.16 (A8); also elsewhere on the board
A9: U6.17 (A9); also elsewhere on the board
A10: U6.18 (A10); also elsewhere on the board
A11: U6.19 (A11); also elsewhere on the board
A12: U6.21 (A12); also elsewhere on the board
A13: U6.22 (A13); also elsewhere on the board
A14: U34.1 (A14); also elsewhere on the board
A15: U34.2 (A15); also elsewhere on the board
Bphi2: U35.9 (CLK1); also elsewhere on the board
CLKIN: Q4.1 (E), R18.1, U6.2 (CLK), YB1.8 (OUT)
COLOR_OSC: C206.2, L37.2, U21.3 (CK1), W2.1 (A); also elsewhere on the board
D0: U9.2 (DI), U9.14 (DO), U26.2 (DI), U26.14 (DO); also elsewhere on the board
D1: U10.2 (DI), U10.14 (DO), U27.2 (DI), U27.14 (DO); also elsewhere on the board
D2: U11.2 (DI), U11.14 (DO), U28.2 (DI), U28.14 (DO); also elsewhere on the board
D3: U12.2 (DI), U12.14 (DO), U29.2 (DI), U29.14 (DO); also elsewhere on the board
D4: U13.2 (DI), U13.14 (DO), U30.2 (DI), U30.14 (DO); also elsewhere on the board
D5: U14.2 (DI), U14.14 (DO), U31.2 (DI), U31.14 (DO); also elsewhere on the board
D6: U15.2 (DI), U15.14 (DO), U32.2 (DI), U32.14 (DO); also elsewhere on the board
D7: U16.2 (DI), U16.14 (DO), U33.2 (DI), U33.14 (DO); also elsewhere on the board
FA14: U6.23 (FA14), U34.16 (FA14)
FA15: U6.24 (FA15), U34.17 (FA15)
GND: C29.1, C32.2, C33.2, C34.1, C35.1, C36.1, C37.1, C38.1, C39.1, C40.1, C41.1, C58.1, C60.1, C61.1, C101.2, C103.2, C105.1, C113.1, C114.1, C115.1, C116.1, C117.1, C118.1, C119.1, C120.1, C206.1, Q6.1 (E), R18.2, R27.2, R29.2, R69.1, U6.20 (GND), U9.16 (GND), U10.16 (GND), U11.16 (GND), U12.16 (GND), U13.16 (GND), U14.16 (GND), U15.16 (GND), U16.16 (GND), U21.7 (GND), U26.16 (GND), U27.16 (GND), U28.16 (GND), U29.16 (GND), U30.16 (GND), U31.16 (GND), U32.16 (GND), U33.16 (GND), U34.7 (NC), U34.8 (NC), U34.9 (NC), U34.10 (GND), U35.2 (A), U35.3 (B), U35.4 (C), U35.5 (D), U35.6 (Mode), U35.7 (GND), U35.8 (CLK2), YB1.7 (GND); also elsewhere on the board
HALT: U34.13 (HALT), U35.1 (SDI); also elsewhere on the board
MHALT: U34.11 (MHALT), U35.13 (QA)
unnamed: C59.2, Y2.2
unnamed: C111.1, L8.1, R71.1, Y2.1
unnamed: C61.2, C111.2, L8.2
unnamed: C33.1, Q4.2 (B), Q5.3 (C), R26.2, YA1.2
unnamed: C32.1, Q5.2 (B), R28.2, R29.1, YA1.1
unnamed: Q5.1 (E), R27.1
unnamed: Q6.2 (B), R69.2, R70.1, R71.2
unnamed: C29.2, L103.1, U6.40 (VCC)
unnamed: U21.5 (Q1), U21.11 (CK2)
unnamed: U21.2 (D1), U21.6 (~Q1)
unnamed: U21.8 (~Q2), U21.12 (D2)
unnamed: C59.1, C60.2, R73.1, U21.9 (Q2)
unnamed: R111.1, U34.14 (~CASBNK)
unnamed: R110.1, U34.15 (~CASMAN)
OSC: L37.1, U6.37 (OSC)
PAL: Q6.3 (C), R70.2, R72.1, W2.2 (B); also elsewhere on the board
PB2: U34.3 (BA14); also elsewhere on the board
PB3: U34.4 (BA15); also elsewhere on the board
PB4: U34.5 (CBE); also elsewhere on the board
PB5: U34.18 (VBE); also elsewhere on the board
Phi2: U6.5 (O2), U34.19 (O2); also elsewhere on the board
R/~W: U6.38 (R/~W); also elsewhere on the board
~CASINH: U6.4 (~CASINH); also elsewhere on the board
~CAS: U6.35 (~CAS), U34.6 (~CAS)
~EXTSEL: U6.3 (EXTSEL); also elsewhere on the board
~RST: U6.39 (~RST); also elsewhere on the board

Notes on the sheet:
U35 IS AN ALTERNATIVE FOR THE CUSTOM GATE ARRAY AND MUST BE USED IN COMBINATION WITH PAL16L8 OR GAL16V8 https://atarimax.com/jindroush.atari.org/data/achips/co25953-pal16l8.vhd
ADD JUMPER FOR W2^{*} FOR NTSC
NOT REQUIRED FOR NTSC
Y1 NTSC - 14.31818 MHz PAL - 14.187576 MHz
When L37 is a resistor then C206 is not populated
ALTERNATE TO

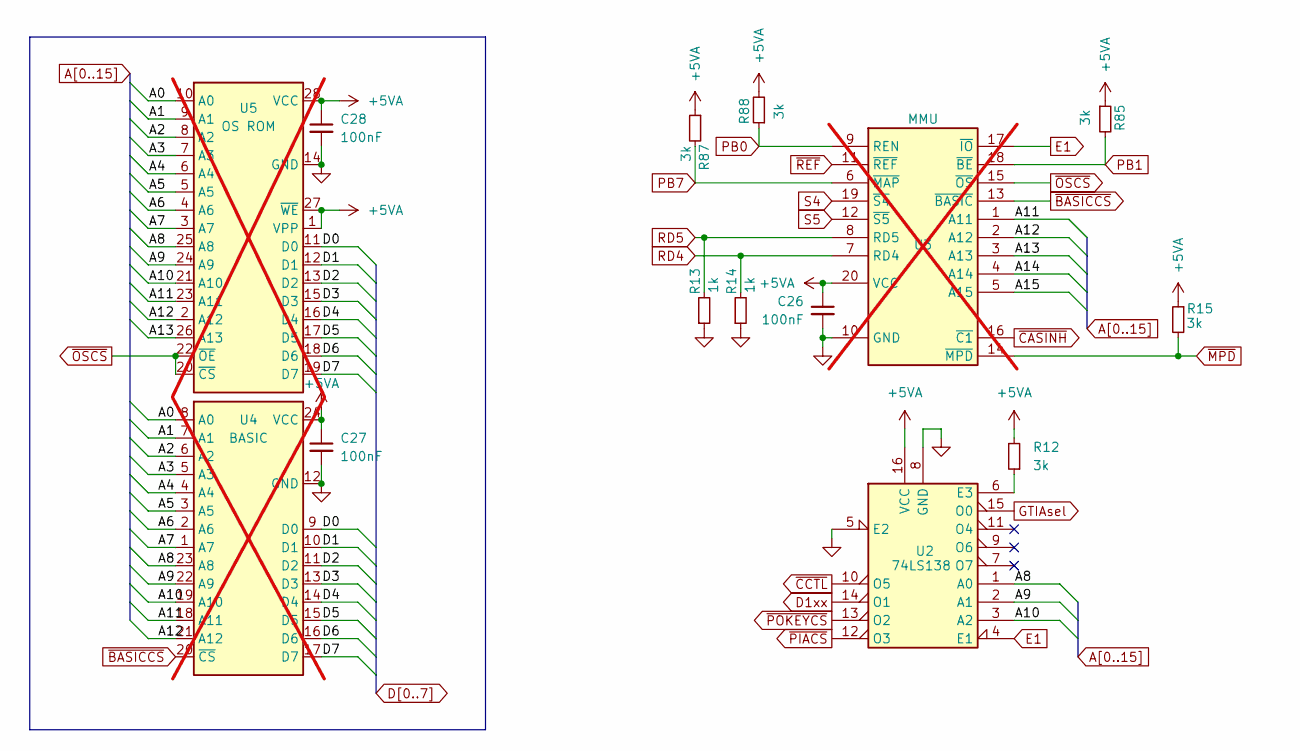
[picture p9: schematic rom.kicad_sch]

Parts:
C26, C27, C28: 100nF; C_Axial_L5.1mm_D2.7mm_P12.72mm_Horizontal; DigiKey 1109PHCT-ND
R12, R15, R85, R87, R88: 3k; R_Axial_L9.0mm_D2.7mm_P12.70mm_Horizontal; DigiKey CF14JT3K00CT-ND
R13, R14: 1k; R_Axial_L9.0mm_D2.7mm_P12.70mm_Horizontal; DigiKey CF14JT1K00CT-ND
U2: 74LS138; DIP-16_W7.62mm; DigiKey 296-1639-5-ND
U3: MMU; DIP-20_W7.62mm; not fitted
U4: BASIC; DIP-24_W15.24mm; not fitted
U5: OS ROM; DIP-28_W15.24mm; not fitted

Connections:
+5VA: C26.1, C27.1, C28.1, R12.2, R15.1, R85.1, R87.1, R88.2, U2.16 (VCC), U3.20 (VCC), U4.24 (VCC), U5.1 (VPP), U5.27 (~WE), U5.28 (VCC); also elsewhere on the board
A0: U4.8 (A0), U5.10 (A0); also elsewhere on the board
A1: U4.7 (A1), U5.9 (A1); also elsewhere on the board
A2: U4.6 (A2), U5.8 (A2); also elsewhere on the board
A3: U4.5 (A3), U5.7 (A3); also elsewhere on the board
A4: U4.4 (A4), U5.6 (A4); also elsewhere on the board
A5: U4.3 (A5), U5.5 (A5); also elsewhere on the board
A6: U4.2 (A6), U5.4 (A6); also elsewhere on the board
A7: U4.1 (A7), U5.3 (A7); also elsewhere on the board
A8: U2.1 (A0), U4.23 (A8), U5.25 (A8); also elsewhere on the board
A9: U2.2 (A1), U4.22 (A9), U5.24 (A9); also elsewhere on the board
A10: U2.3 (A2), U4.19 (A10), U5.21 (A10); also elsewhere on the board
A11: U3.1 (A11), U4.18 (A11), U5.23 (A11); also elsewhere on the board
A12: U3.2 (A12), U4.21 (A12), U5.2 (A12); also elsewhere on the board
A13: U3.3 (A13), U5.26 (A13); also elsewhere on the board
A14: U3.4 (A14); also elsewhere on the board
A15: U3.5 (A15); also elsewhere on the board
D0: U4.9 (D0), U5.11 (D0); also elsewhere on the board
D1: U4.10 (D1), U5.12 (D1); also elsewhere on the board
D1xx: U2.14 (O1); also elsewhere on the board
D2: U4.11 (D2), U5.13 (D2); also elsewhere on the board
D3: U4.13 (D3), U5.15 (D3); also elsewhere on the board
D4: U4.14 (D4), U5.16 (D4); also elsewhere on the board
D5: U4.15 (D5), U5.17 (D5); also elsewhere on the board
D6: U4.16 (D6), U5.18 (D6); also elsewhere on the board
D7: U4.17 (D7), U5.19 (D7); also elsewhere on the board
E1: U2.4 (E1), U3.17 (~IO)
GND: C26.2, C27.2, C28.2, R13.1, R14.1, U2.5 (E2), U2.8 (GND), U3.10 (GND), U4.12 (GND), U5.14 (GND); also elsewhere on the board
GTIAsel: U2.15 (O0); also elsewhere on the board
unnamed: R12.1, U2.6 (E3)
PB0: R88.1, U3.9 (REN); also elsewhere on the board
PB1: R85.2, U3.18 (~BE); also elsewhere on the board
PB7: R87.2, U3.6 (~MAP); also elsewhere on the board
RD4: R14.2, U3.7 (RD4); also elsewhere on the board
RD5: R13.2, U3.8 (RD5); also elsewhere on the board
S4: U3.19 (~S4); also elsewhere on the board
S5: U3.12 (~S5); also elsewhere on the board
~BASICCS: U3.13 (~BASIC), U4.20 (~CS)
~CASINH: U3.16 (~C1); also elsewhere on the board
~CCTL: U2.10 (O5); also elsewhere on the board
~MPD: R15.2, U3.14 (~MPD); also elsewhere on the board
~OSCS: U3.15 (~OS), U5.20 (~CS), U5.22 (~OE)
~PIACS: U2.12 (O3); also elsewhere on the board
~POKEYCS: U2.13 (O2); also elsewhere on the board
~REF: U3.11 (~REF); also elsewhere on the board

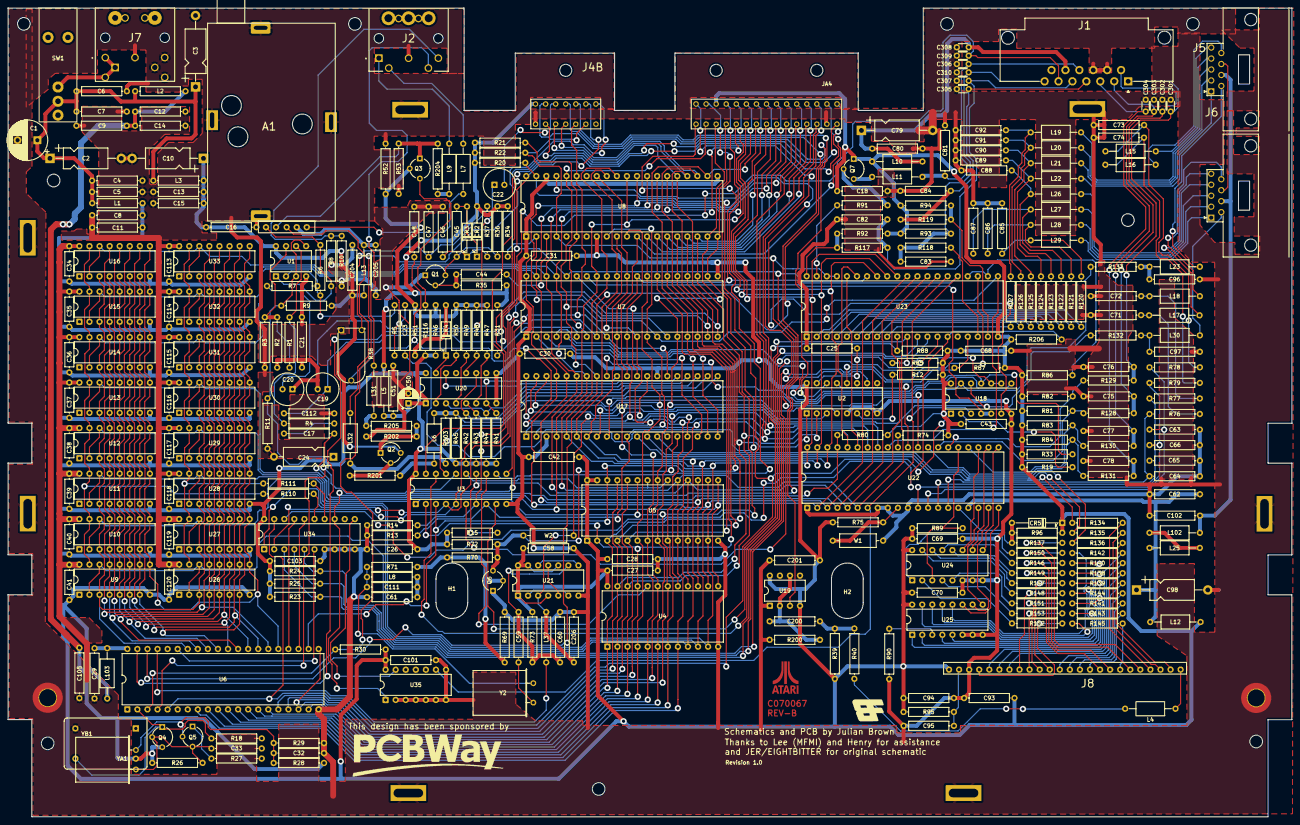
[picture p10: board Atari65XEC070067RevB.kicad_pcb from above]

Board: 2 copper layers, 323.9 x 204.0 mm, 358 parts (0 on the bottom side), 275 nets.

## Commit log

2025-06-19 add ports
    [Atari65XEC070067RevB.kicad_sch]
2025-06-20 complete schematic
    [Atari65XEC070067RevB.kicad_sch]
2025-06-20 start layout
    [Atari65XEC070067RevB.kicad_pcb, Atari65XEC070067RevB.kicad_sch]
2025-06-20 initial pcb layout
    [Atari65XEC070067RevB.kicad_sch]
2025-06-21 locate dram and trace around it
    [Atari65XEC070067RevB.kicad_sch]
2025-06-21 progress routing
    [Atari65XEC070067RevB.kicad_sch]
2025-06-22 update progress
    [Atari65XEC070067RevB.kicad_sch]
2025-06-22 correct wiring of control keys to GTIA
    [Atari65XEC070067RevB.kicad_sch]
2025-06-23 fix ROM positions
    [Atari65XEC070067RevB.kicad_sch]
2025-06-24 fix phi2 wiring
    [Atari65XEC070067RevB.kicad_sch]
2025-06-24 update pcb render
2025-06-26 update fills and footprints
    [Atari65XEC070067RevB.kicad_sch]
2025-06-26 refine board definition
    [Atari65XEC070067RevB.kicad_sch]
2025-06-27 place power circuit components
    [Atari65XEC070067RevB.kicad_sch]
2025-06-27 revise ram chip positions
    [Atari65XEC070067RevB.kicad_sch]
2025-06-29 update u35 and u34 schematic and routing
    [Atari65XEC070067RevB.kicad_sch]
2025-06-30 progress routing, add modulator
    [Atari65XEC070067RevB.kicad_sch]
2025-07-01 more routing
    [Atari65XEC070067RevB.kicad_sch]
2025-07-06 fix din ports
    [Atari65XEC070067RevB.kicad_pcb, Atari65XEC070067RevB.kicad_sch]
2025-07-06 add sio port
    [Atari65XEC070067RevB.kicad_pcb, Atari65XEC070067RevB.kicad_sch]
2025-07-07 fix numbering for U6 and U8 (swapped), more routing
    [Atari65XEC070067RevB.kicad_pcb, Atari65XEC070067RevB.kicad_sch]
2025-07-07 finish component placing
    [Atari65XEC070067RevB.kicad_pcb, Atari65XEC070067RevB.kicad_sch]
2025-07-07 refine rf modulator footprint
    [Atari65XEC070067RevB.kicad_pcb]
2025-07-11 progress routing, update README, add branding
    [Atari65XEC070067RevB.kicad_pcb, Atari65XEC070067RevB.kicad_sch]
2025-07-14 refine footprints
    [Atari65XEC070067RevB.kicad_pcb, Atari65XEC070067RevB.kicad_sch]
2025-07-14 rectify board dimensions
    [Atari65XEC070067RevB.kicad_pcb]
2025-07-15 fix SIO footprint and placement
    [Atari65XEC070067RevB.kicad_pcb]
2025-07-15 set mounting points
    [Atari65XEC070067RevB.kicad_pcb, Atari65XEC070067RevB.kicad_sch]
2025-07-17 complete revision 1
    [Atari65XEC070067RevB.kicad_pcb]
2025-07-24 provide component part nubmers for digikey
    [Atari65XEC070067RevB.kicad_pcb, Atari65XEC070067RevB.kicad_sch]
2025-07-25 provide BOM for digikey
    [Atari65XEC070067RevB.csv]
2025-09-25 tidy up schematic
    [Atari65XEC070067RevB.kicad_pcb, Atari65XEC070067RevB.kicad_sch, video.kicad_sch]
2025-09-28 tidy up
    [Atari65XEC070067RevB.kicad_sch, IO.kicad_sch, power.kicad_sch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]
2025-09-29 tidy up video
    [Atari65XEC070067RevB.kicad_sch, clocks.kicad_sch, video.kicad_sch]
2025-09-29 complete tidy up
    [Atari65XEC070067RevB.kicad_sch, IO.kicad_sch, clocks.kicad_sch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]
